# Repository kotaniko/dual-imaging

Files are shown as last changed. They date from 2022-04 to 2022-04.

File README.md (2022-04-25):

# Dual-Imaging Display
This prototype is developed in partial fulfillment for a Master's degree to prove that fiber-optic interconnection is a suitable high-speed interconnection for CubeSat platforms. The thesis is available [here](https://gatech.edu).

## Introduction
This repository contains the development details of dual-imaging display using the BF4M fiber-optic module with FPGAs and Raspberry Pi Compute Module 4. The goal of this prototype is to demonstrate the high-speed interconnection using a fiber-optic transceiver for CubeSat platforms.

## Hardware
* Artix-7 FPGA module from Trenz Electronic: [TE0714-03-50-2IAC6](https://shop.trenz-electronic.de/en/TE0714-03-50-2IAC6-FPGA-Module-with-Xilinx-Artix-7-XC7A50T-2CSG325I-1.8V-Configuration-4-x-3-cm)

* [Raspberry Pi Compute Module 4](https://www.raspberrypi.com/products/compute-module-4)

* [BF4M](https://www.hirose.com/product/series/BF4M) fiber-optic module from Hirose Electronic

* [Pcam 5C](https://digilent.com/shop/pcam-5c-5-mp-fixed-focus-color-camera-module) camera module from Digilent

## System Architecture
Below shows the overview of the dual-imaging display system.

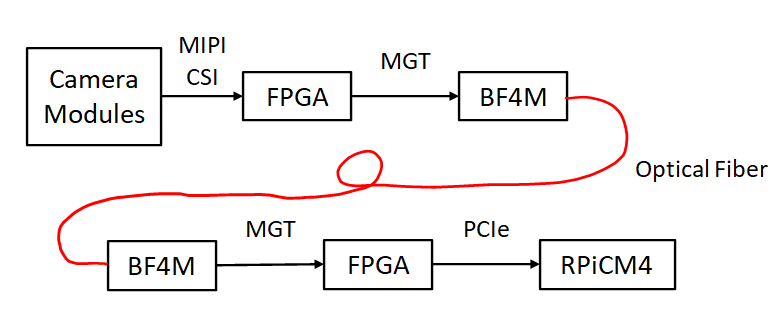
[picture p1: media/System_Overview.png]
System Overview


MIPI CSI-2 Rx Subsystem IP core is used for interfacing with the camera modules, and Aurora8B10B Ip core for interfacing with the fiber-optic transceiver operating up to 6.25 Gbps. On the receiver FPGA, DMA/Bridge Subsystem for PCI Express IP core is used for interfacing with the Raspberry Pi Compute Module 4 over PCIe.

Post-synthesis re-routing on the RX FPGA is needed for GTP clock signals as Aurora8B10B and PCIe core require different clock source. The details are explained in **Vivado/README.md**.

## Images of the Prototype

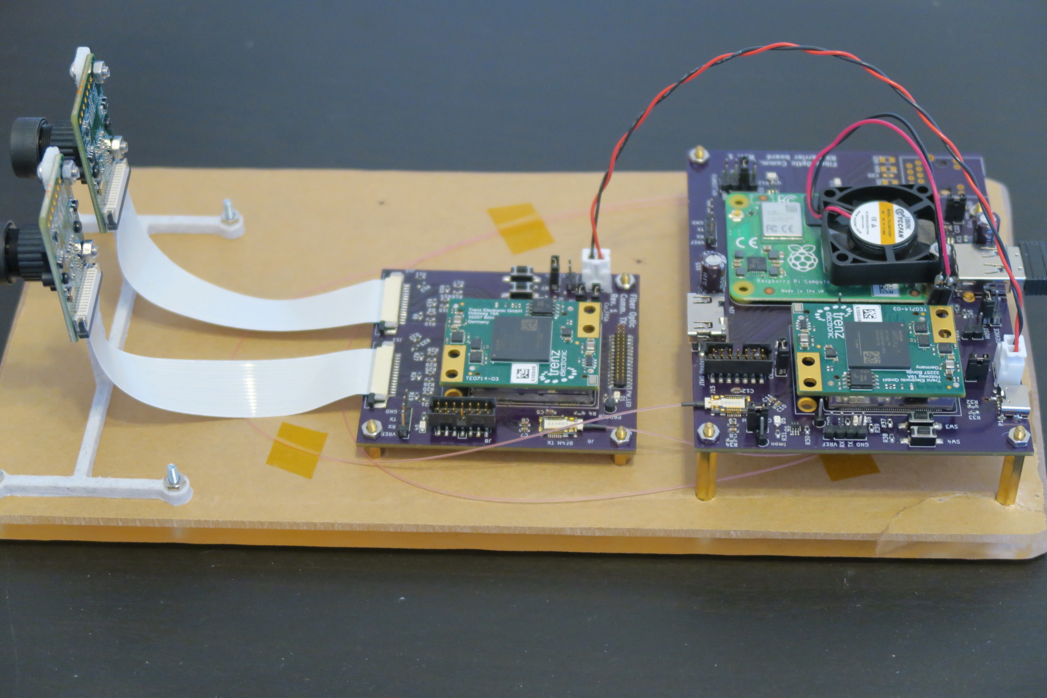
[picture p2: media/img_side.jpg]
Side view


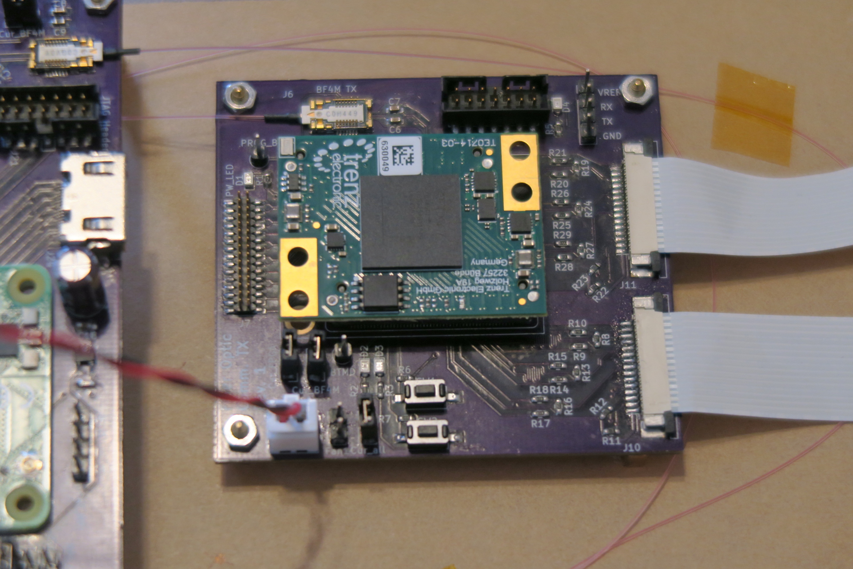
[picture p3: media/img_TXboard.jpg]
TX board


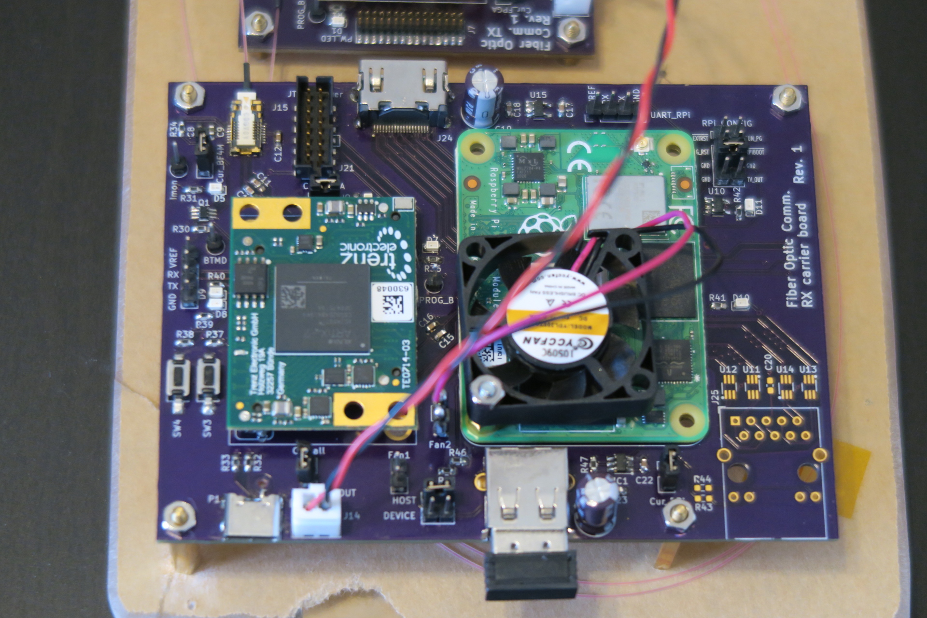
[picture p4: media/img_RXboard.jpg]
RX board


## Demonstration Video
Below video demonstrates that the two camera data stream are transmitted to the Raspberry Pi Compute Module 4 at 1.0 Gbps. The RPiCM4 was capable of receiving the data stream to /dev/null at 2.0 Gbps, but the maximum data rate to write the data stream to its RAM was 1.0 Gbps.

https://user-images.githubusercontent.com/22487346/164984304-3e48e70a-c83b-4c12-9497-3e3b185fa539.mov

The validation method discussed in the thesis demonstrated that the BF4M fiber-optic module achieved the maximum data rate of 6.25 Gbps at the power consumption of 90 mW.

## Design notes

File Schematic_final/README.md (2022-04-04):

# Schematic of the final prototype board

CAD design software: KiCad 6.0

The signals shown below are re-routed after fabrication. This directory contains the modified schematic design. The pdf of the schematic is available in ../Docs directory.

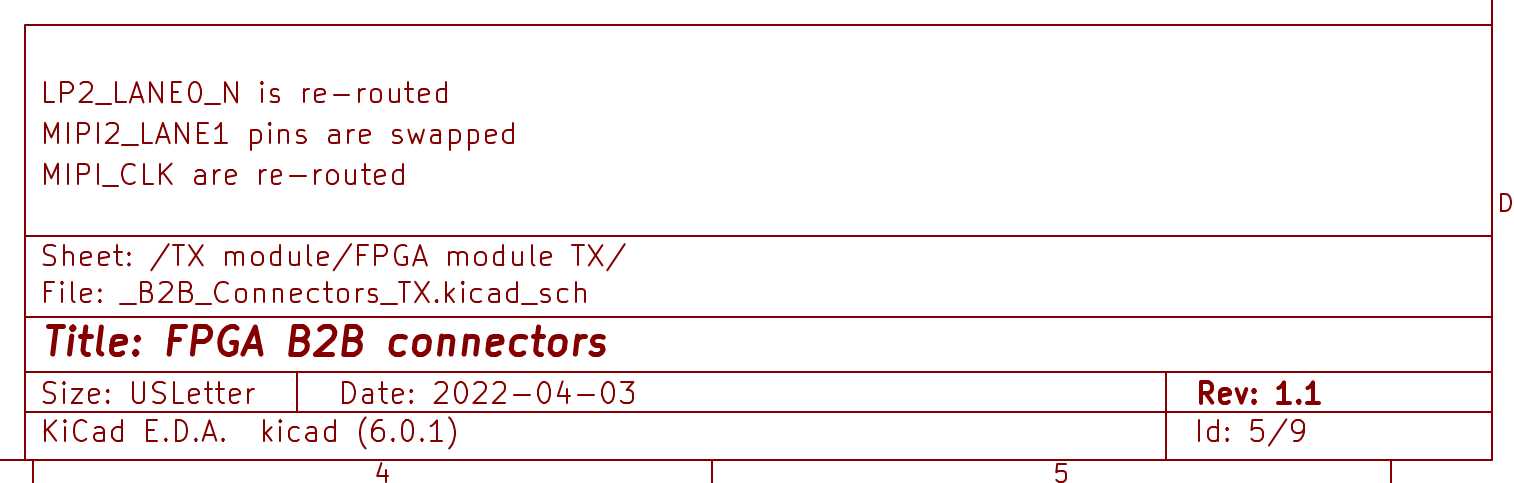
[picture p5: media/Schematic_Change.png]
Schematic Change


Open Root.kicad_pro project file with KiCad 6.0 to design this schematic.

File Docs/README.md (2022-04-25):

# Document

* BlockDesign_aurora2pcie.pdf
    - Block design of the RX FPGA
* BlockDesign_mipiCsi2aurora.pdf
    - Block design of the TX FPGA
* Schematic_fabricated.pdf
    - Schematic of the fabricated PCB
* Schematic_final.pdf
    - Final schematic of the prototype board as some signals are re-routed after fabrication

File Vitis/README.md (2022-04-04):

# Vitis development

Software: Vitis 2021.2

Run createVitisProject.bat to build an application project for the TX board (Windows only). This batch file runs create_project_mipiCsi2aurora.tcl script.

After the project is successfully built, the script launches the Vitis, and the welcome page shown below appears.

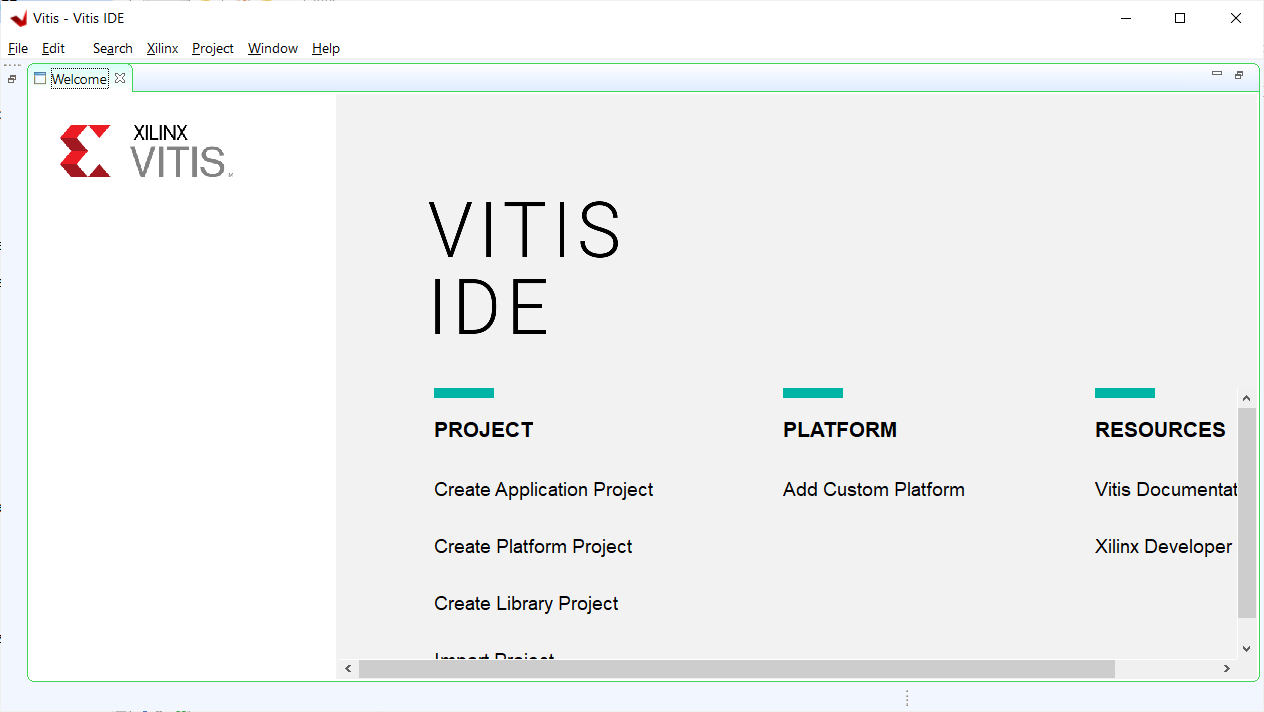
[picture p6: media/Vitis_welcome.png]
Vitis welcome page


Close the welcome page, and you will see the application project shown below.

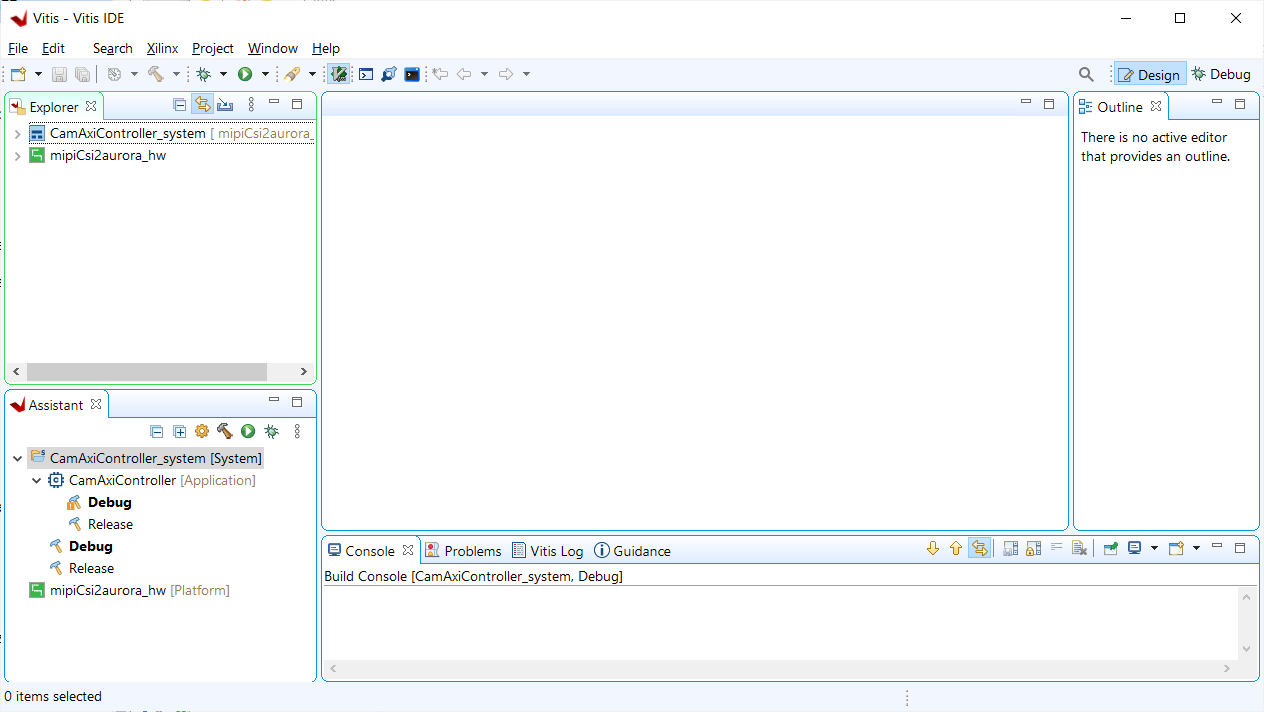
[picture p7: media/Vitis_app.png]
Vitis app page


You can now start working on the software development for Microblaze integrated in the TX board.

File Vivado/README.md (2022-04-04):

# Vivado Development

Software: Vivado 2021.2

Run create_project_mipiCsi2aurora.bat to build a Vivado project for the TX board (Windows only). This batch file runs create_project_mipiCsi2aurora.tcl script. Similarly, run create_project_aurora2pcie.bat to build a Vivado project for the RX board. Running the project creation tcl scripts for other version of Vivado may produce error upon execution. Modify the tcl scripts accordingly by replacing the version number with the appropriate one.

Successful execution of the script will launch the Vivado project looking similar to the below.

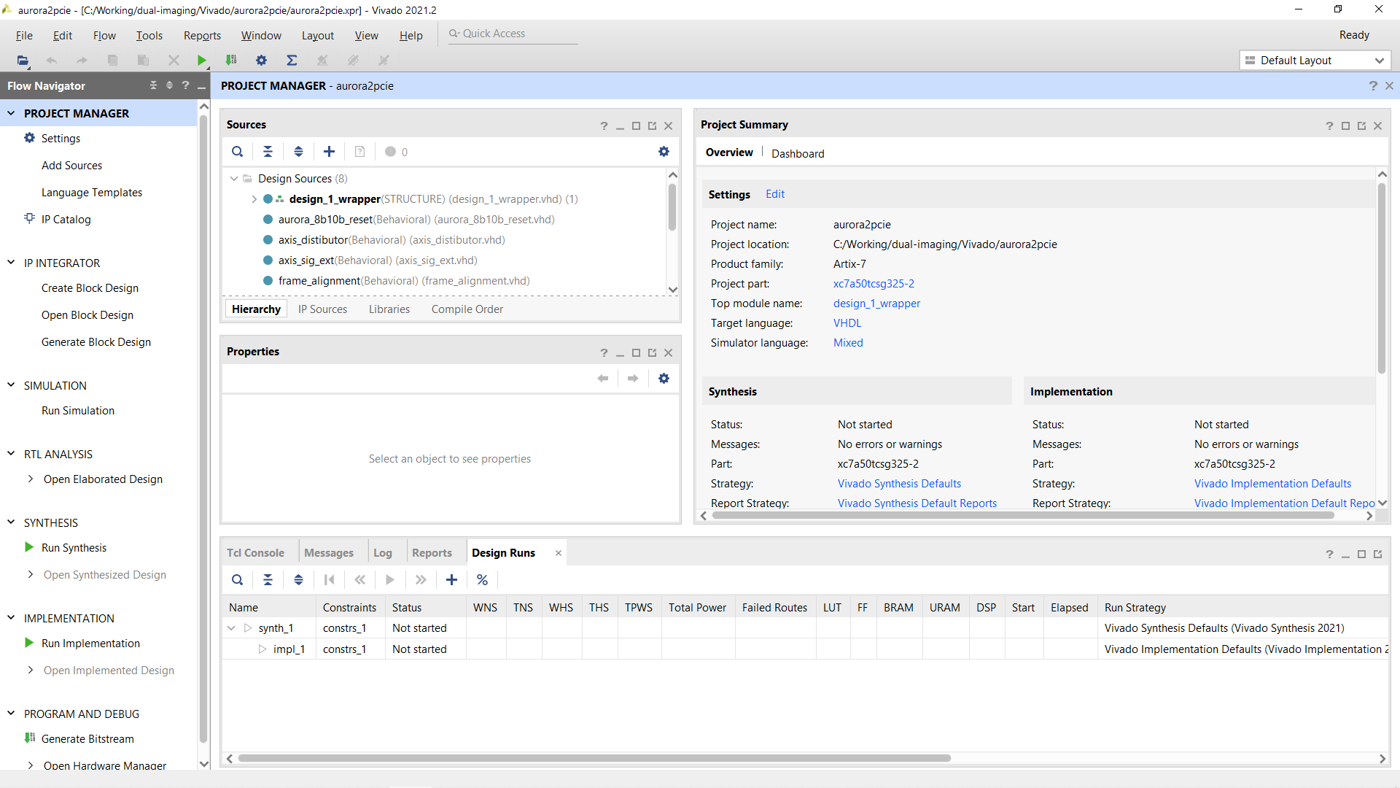
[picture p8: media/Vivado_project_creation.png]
Vivado Project Creation


create_BD_[mipiCsi2aurora/aurora2pcie].tcl are available for those who want to just create the block design. Overviews of the block design for TX/RX board are available under ../Docs directory.

## Directories

* bitstream
    - bitstream files for the TX/RX board generated by Vivado

* hardwareDesign
    - FPGA hardware binary for the TX board exported from Vivado

* memoryConfig
    - memory contents for flash memory on the TE0714 module

* my_constrs/my_rtl/my_tcl
    - source files used in the projects, mipiCsi2aurora and aurora2pcie

## aurora2pcie Project Guide

The Aurora8B10B and PCIe core uses PLL0 by default. Since they require different clock frequency, one of them must use PLL1. This conflict is addressed by running tcl command after synthesis.

After completing the synthesis, open synthesized design as shown below.

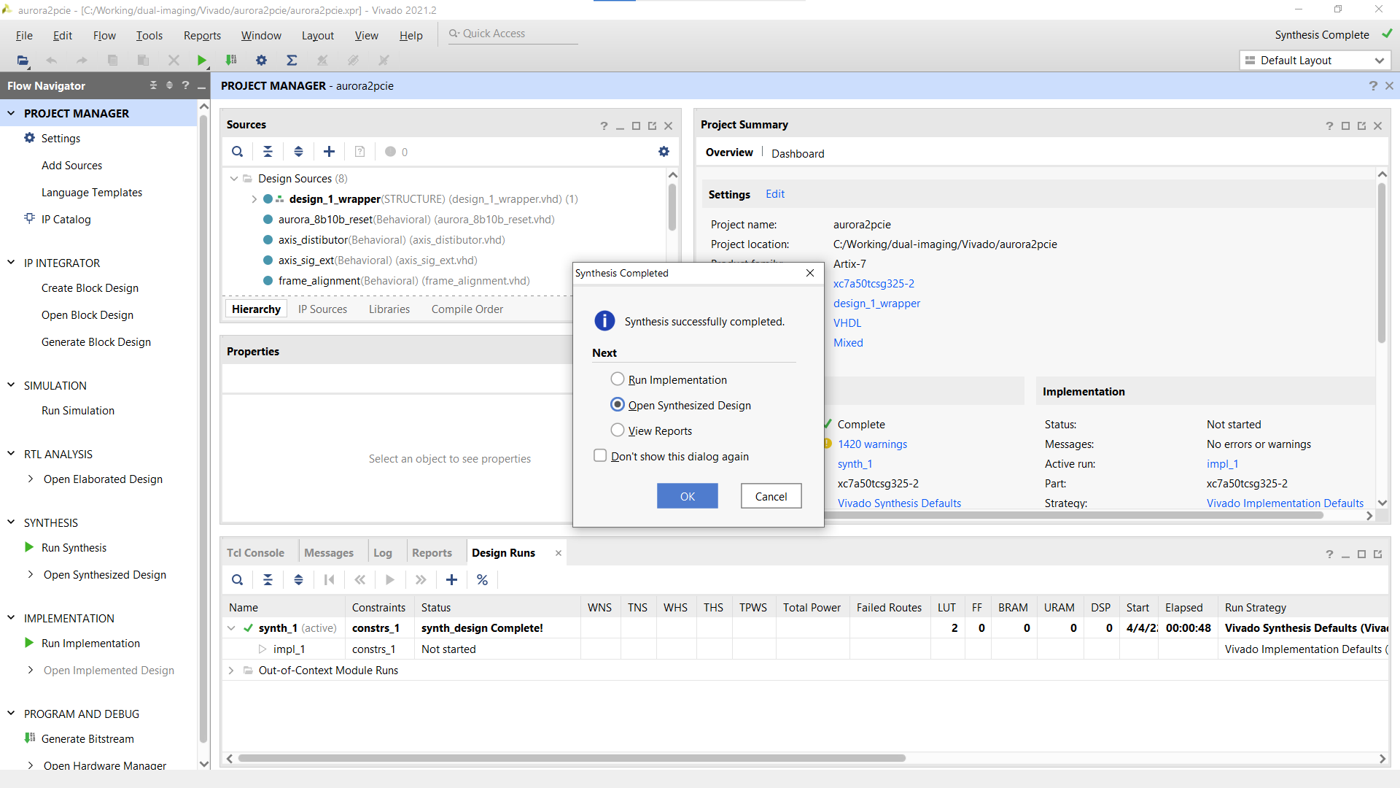
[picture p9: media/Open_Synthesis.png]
Open Synthesis


This will open the Synthesized Design window. Run my_tcl/aurora_pll1.tcl or copy and paste the content of my_tcl/aurora_pll1.tcl in Tcl Console to make the aurora8B10B IP core on the RX board to use PLL1 instead of PLL0.

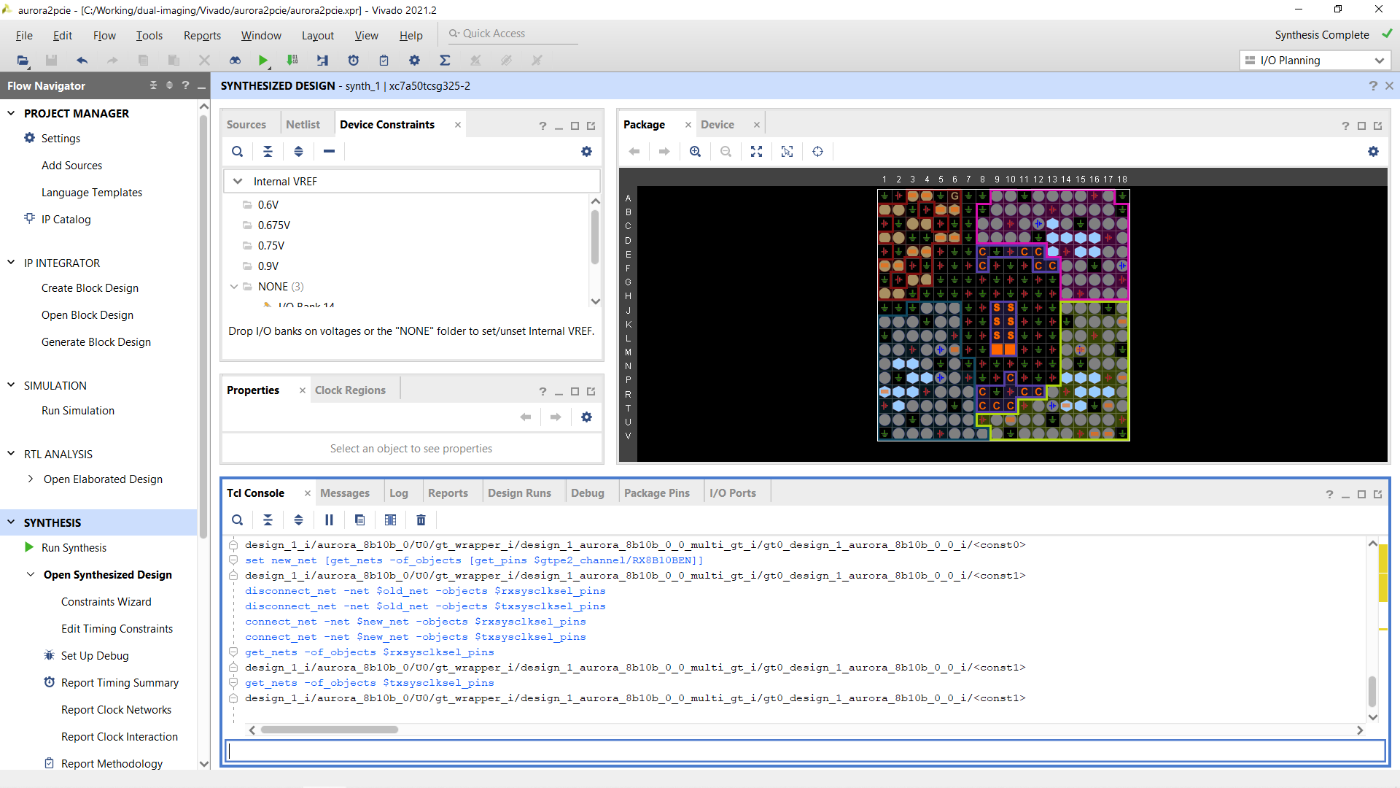
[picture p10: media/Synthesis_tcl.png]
tcl command


Successful execution of the tcl commands should re-route the RXSYSCLKSEL of the GTPE2_CHANNEL primitive to b'11.

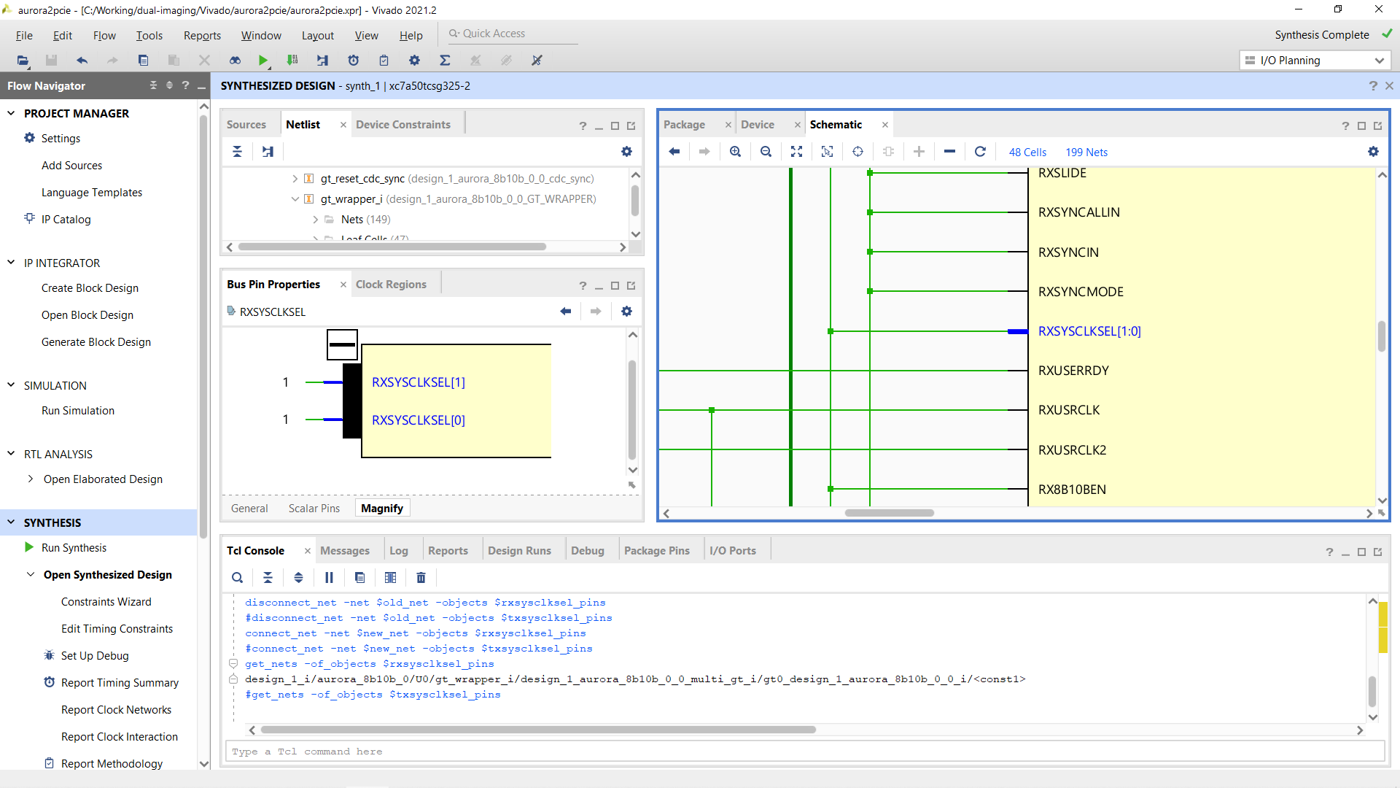
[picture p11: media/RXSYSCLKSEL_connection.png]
RXSYSCLKSEL Connection


Then, continue to run Implementation while the Synthesized Design window opened. Since the synthesized designed is opened in-memory, the net change applied by the above tcl command is also in-memory. Closing the Synthesized Design window will lose the change, and Vivado will implement the design with the original design.

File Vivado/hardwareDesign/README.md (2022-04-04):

# Hardware Design

TX board FPGA hardware binary exported from Vivado

Import *.xsa file in Vitis to create a platform.

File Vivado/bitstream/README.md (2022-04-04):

# Bitstream

Upload mipiCsi2aurora.bit or aurora2pcie.bit to the TX/RX board, respectively, with Vivado Hardware Manager.

*.ltx is a probe file to use VIO and ILA cores from Vivado Hardware Manager.

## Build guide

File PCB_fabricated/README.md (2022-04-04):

# Design files for fabricated PCB

CAD design software: KiCad 6.0

The 3D images of the TX and RX board are shown below. The pdf of the schematic is available in ../Docs directory.

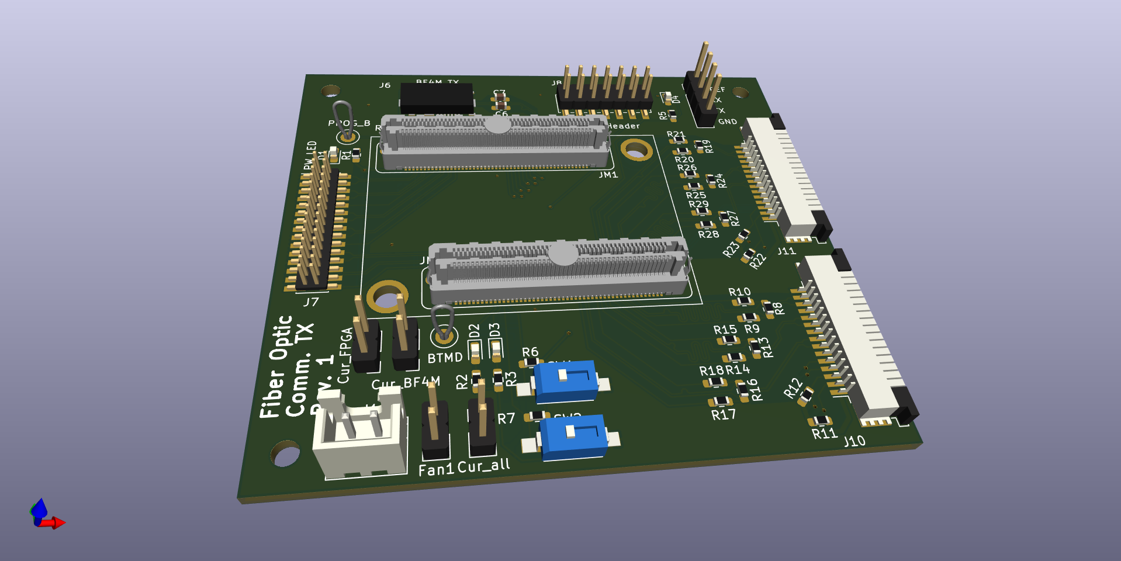
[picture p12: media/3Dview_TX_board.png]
TX board 3d image


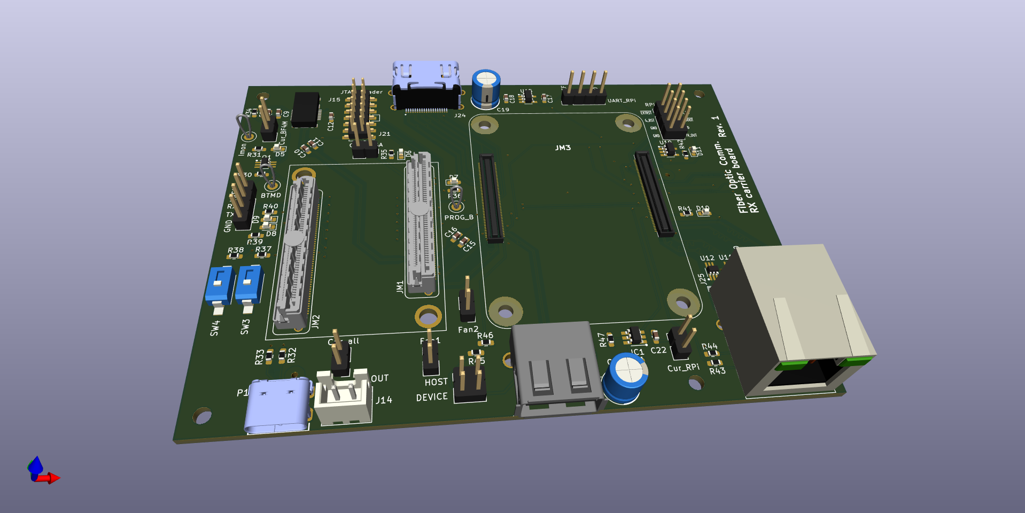
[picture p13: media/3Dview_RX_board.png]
RX board 3d image


Open Root.kicad_pro to design the schematic and [TX/RX]_module.kicad_pro to design [TX/RX] board PCB.

mylib directory contains the project specific symbol, footprint, and 3D model.

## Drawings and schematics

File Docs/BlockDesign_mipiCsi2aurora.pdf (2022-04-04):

### aurora_8b10b_0

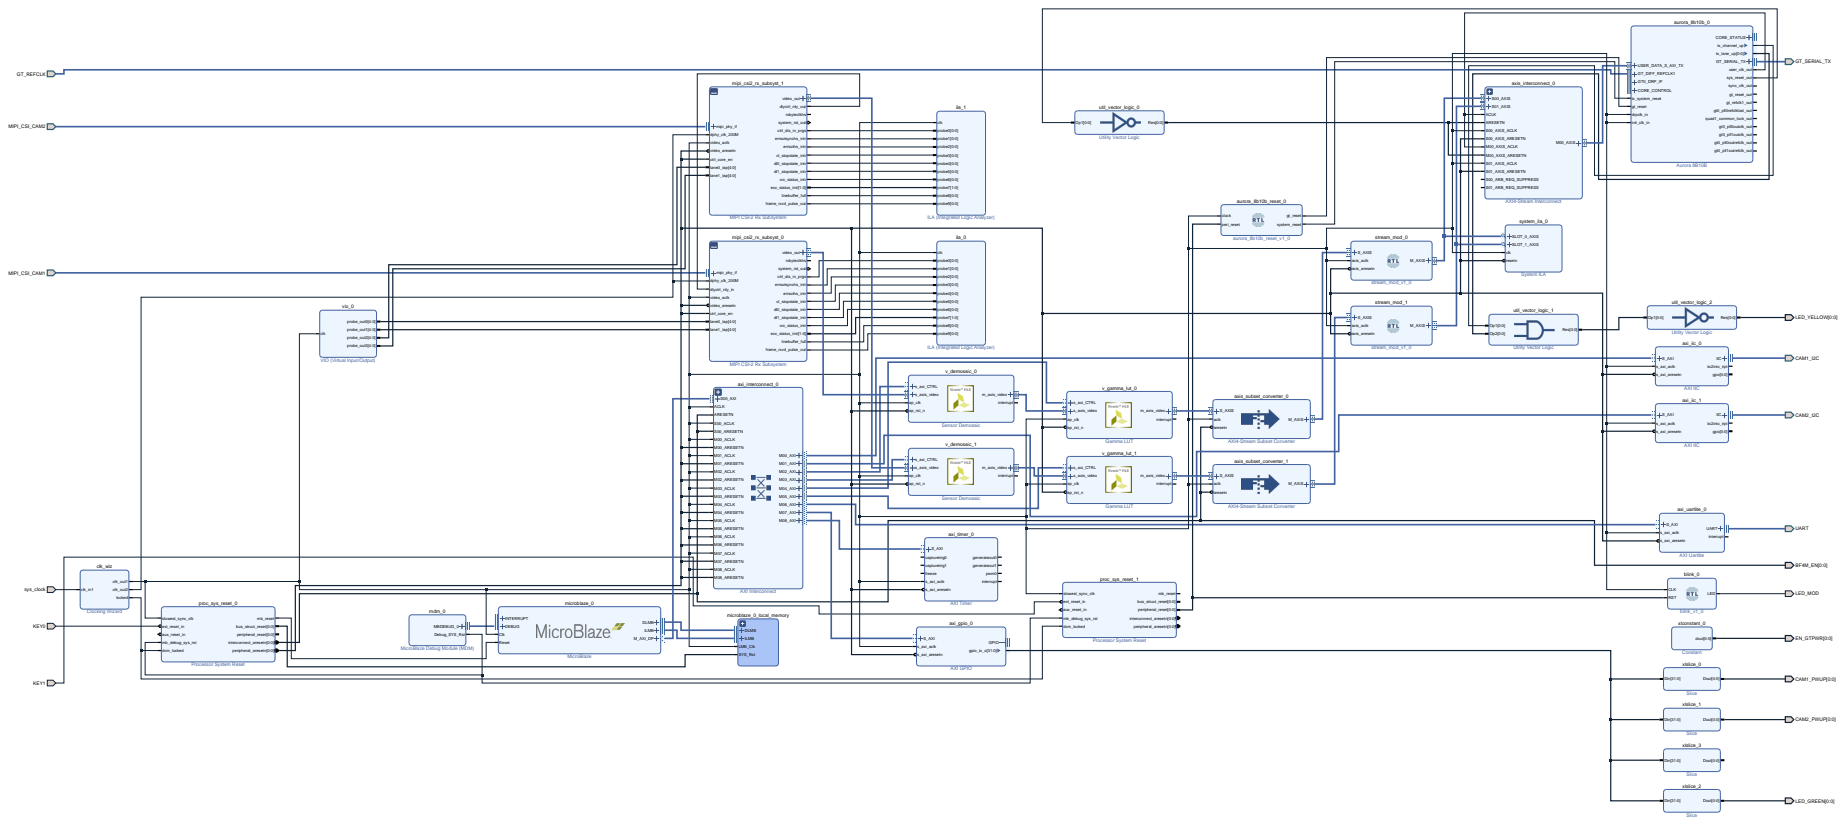
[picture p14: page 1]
CAM1_I2C; CAM1_PWUP[0:0]; CAM2_I2C; CAM2_PWUP[0:0]; EN_GTPWR[0:0]; GT_REFCLK; GT_SERIAL_TX; LED_GREEN[0:0]; LED_YELLOW[0:0]; MIPI_CSI_CAM1; MIPI_CSI_CAM2; UART; aurora_8b10b_reset_0; aurora_8b10b_reset_v1_0; clock peri_reset; gt_reset system_reset; Aurora 8B10B; USER_DATA_S_AXI_TX GT_DIFF_REFCLK1 GT0_DRP_IF; CORE_STATUS; tx_channel_up; tx_lane_up[0:0]; CORE_CONTROL; tx_system_reset gt_reset drpclk_in; init_clk_in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

Utility Vector Logic

MIPI CSI-2 Rx Subsystem

ILA (Integrated Logic Analyzer)
clk probe0[0:0] probe1[0:0] probe2[0:0] probe3[0:0] probe4[0:0] probe5[0:0] probe6[0:0] probe7[1:0] probe8[0:0] probe9[0:0]

axi_iic_0

VIO (Virtual Input/Output)

AXI4-Stream Subset Converter

Processor System Reset

MicroBlaze Debug Module (MDM)

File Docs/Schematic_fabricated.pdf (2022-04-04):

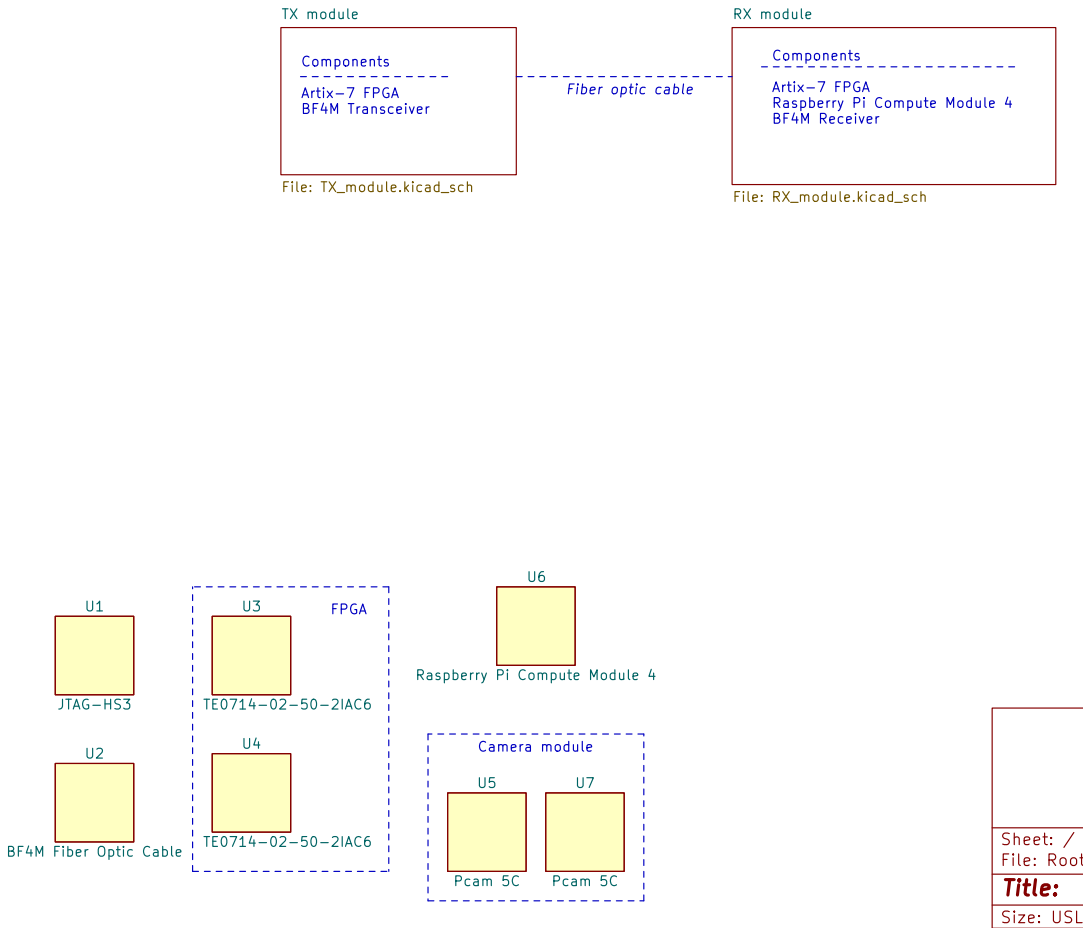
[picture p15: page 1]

Components Artix-7 FPGA Raspberry Pi Compute Module 4 BF4M Receiver Components Artix-7 FPGA

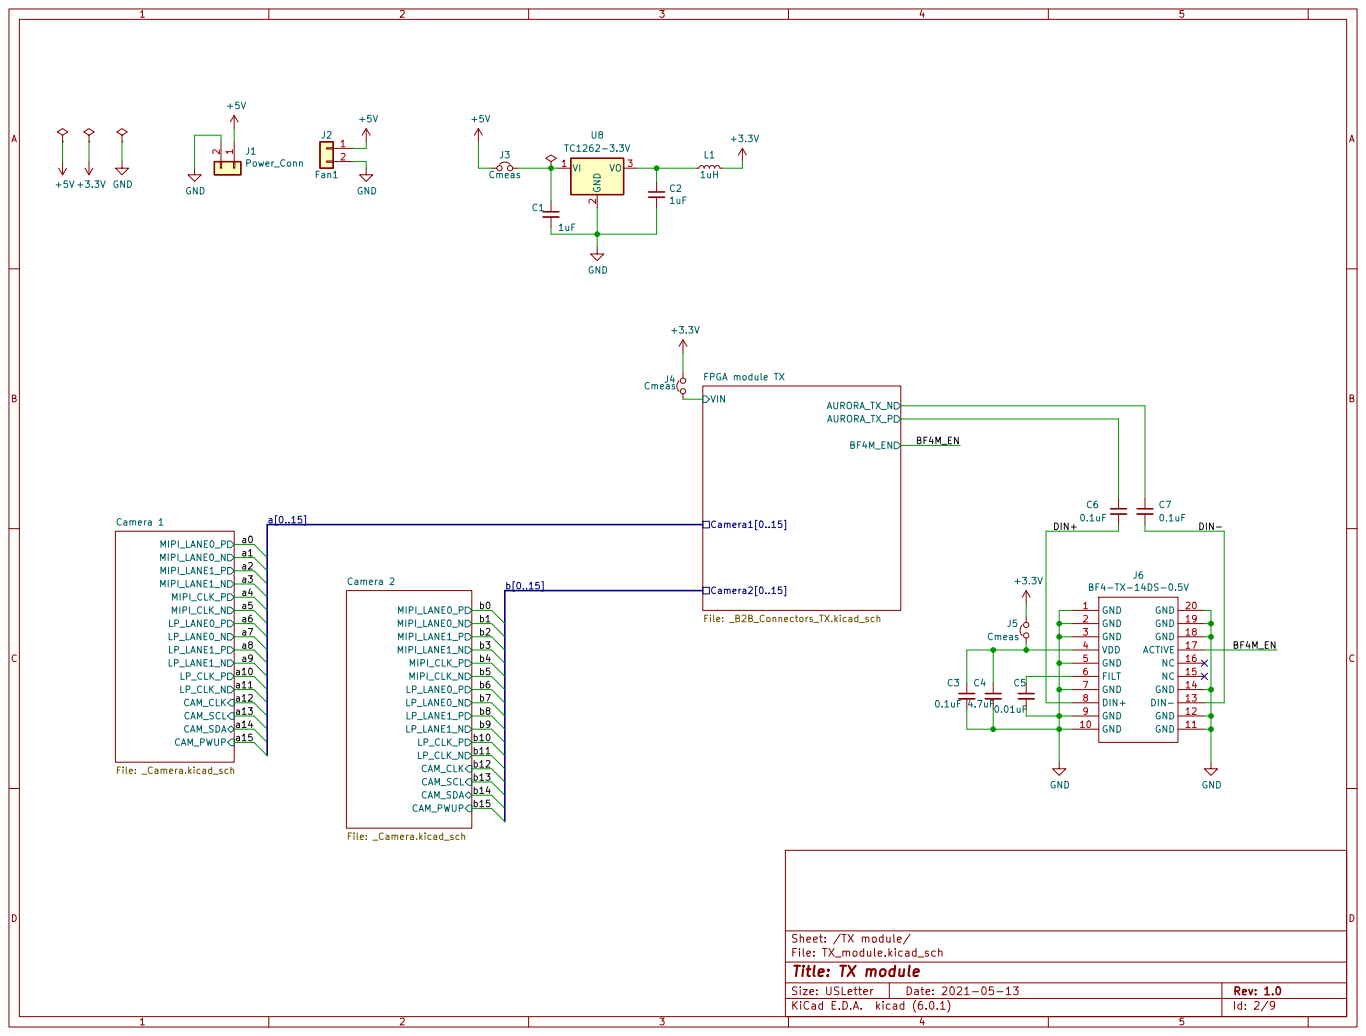
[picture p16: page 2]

File: TX_module.kicad_sch Sheet: /TX module/ MIPI_LANE0_N MIPI_LANE0_P MIPI_LANE1_N MIPI_LANE1_P MIPI_CLK_N MIPI_CLK_P CAM_PWUP CAM_CLK CAM_SCL CAM_SDA

Id: 2/9 Title: TX module

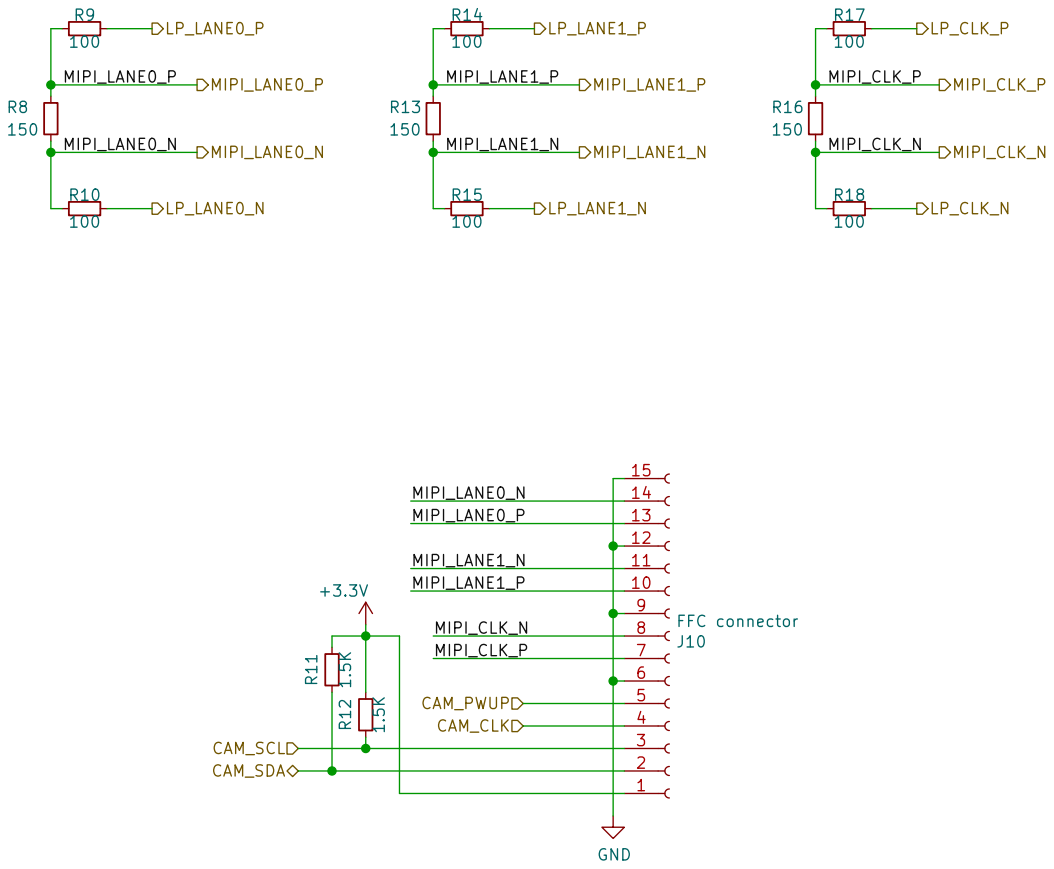
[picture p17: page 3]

Id: 3/9 Title: Camera module

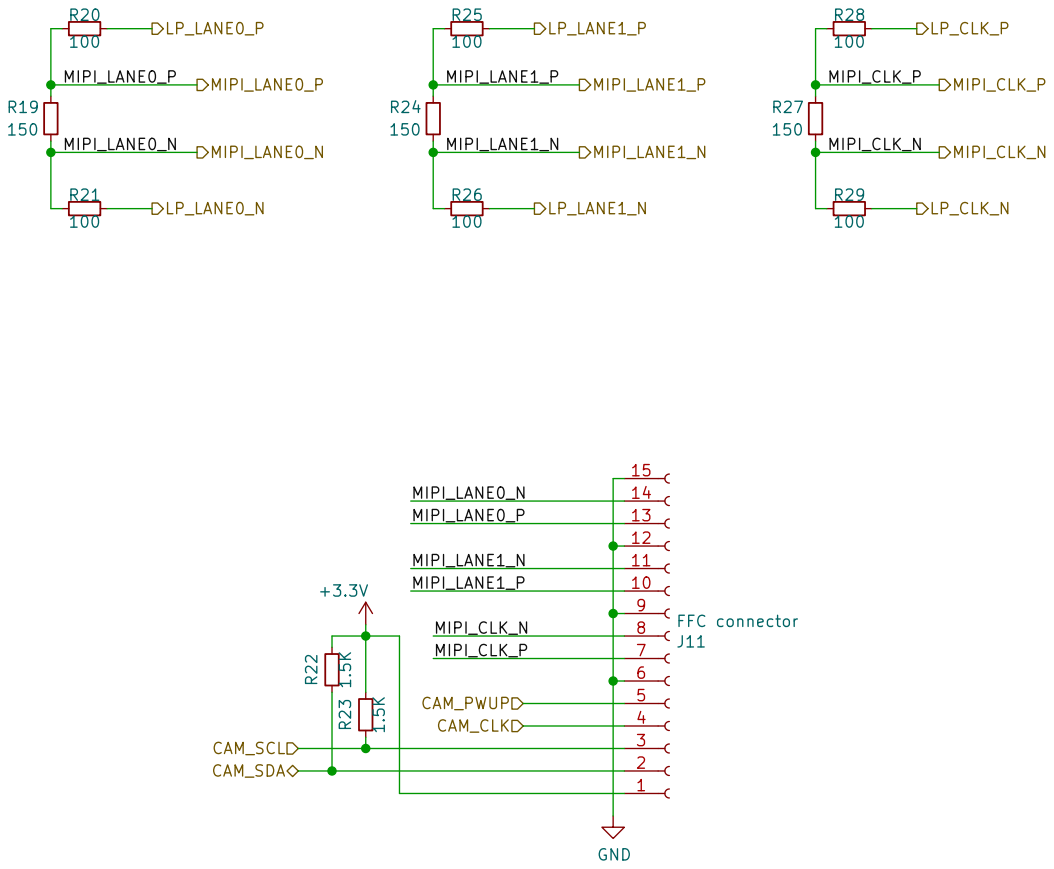
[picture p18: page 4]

Id: 4/9 Title: Camera module

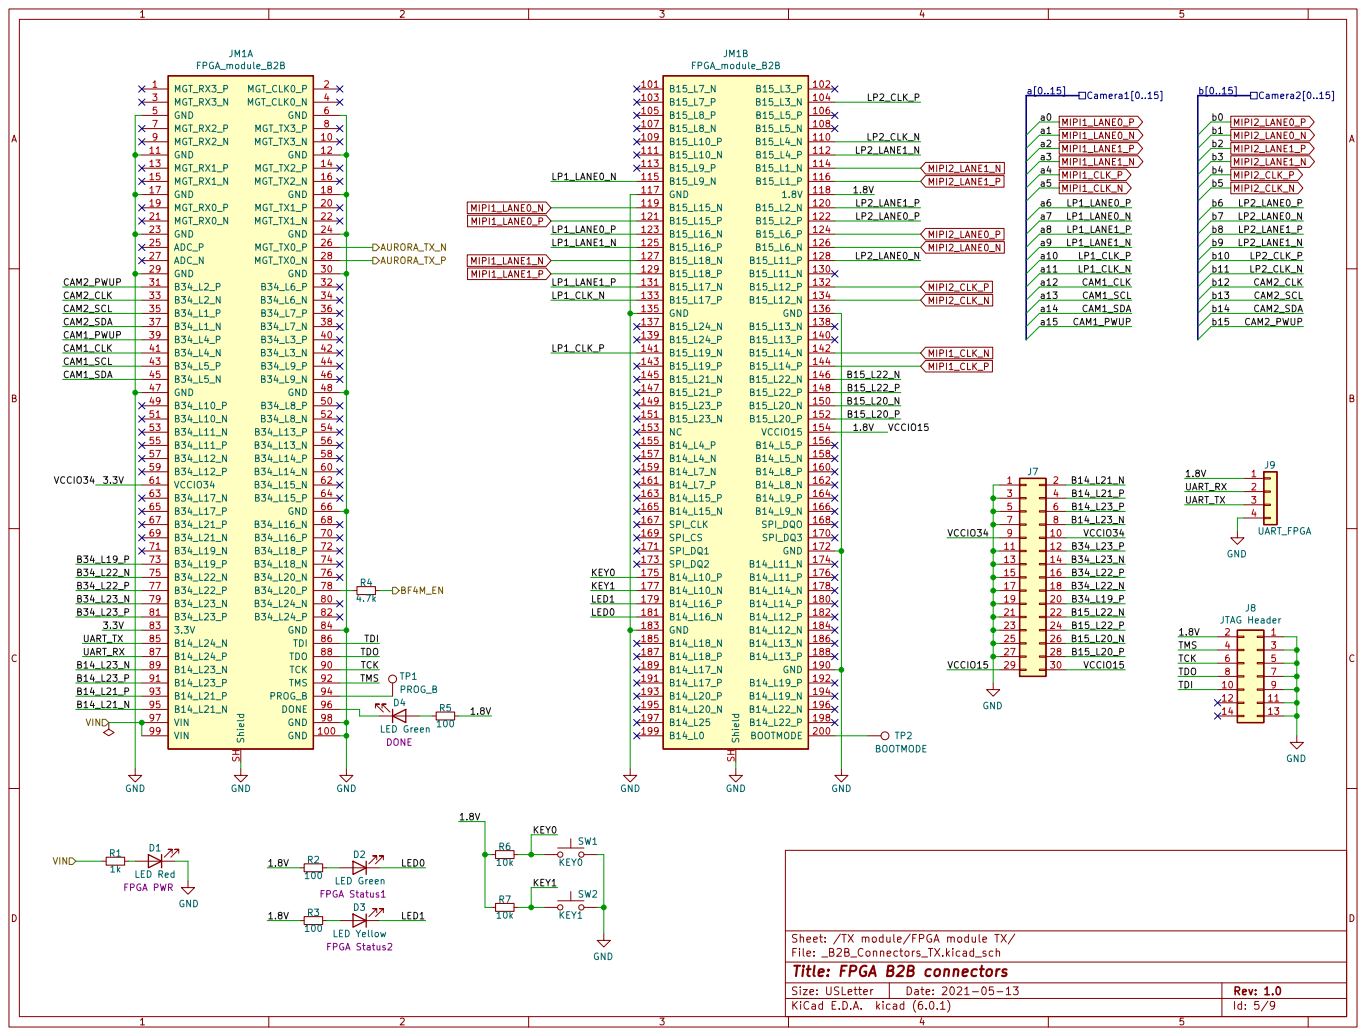
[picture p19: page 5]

Id: 5/9 Title: FPGA B2B connectors

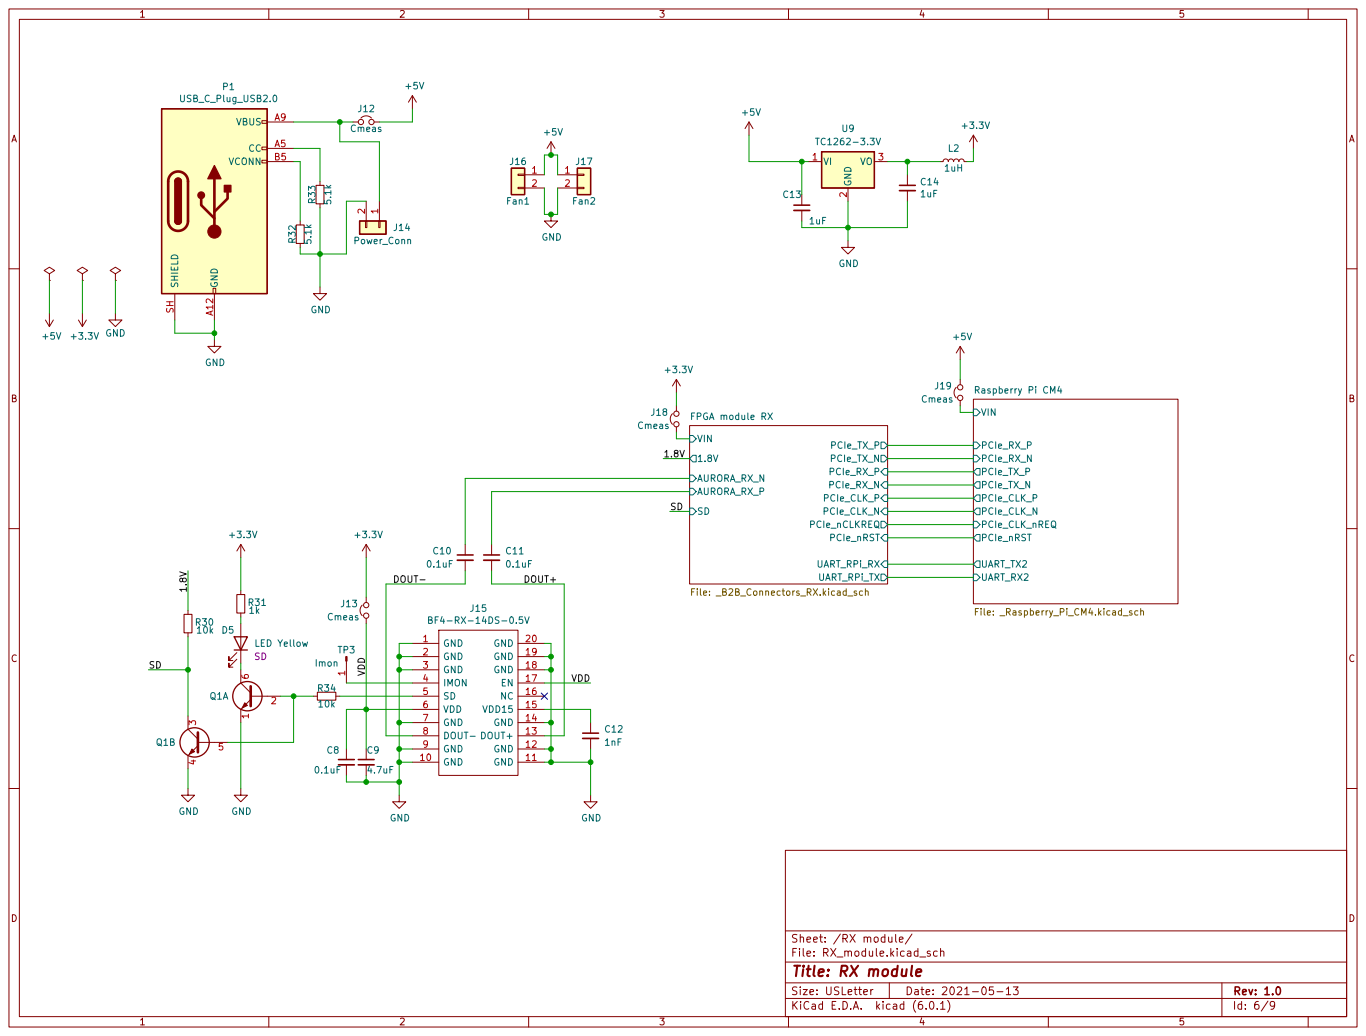
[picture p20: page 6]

Id: 6/9 Title: RX module

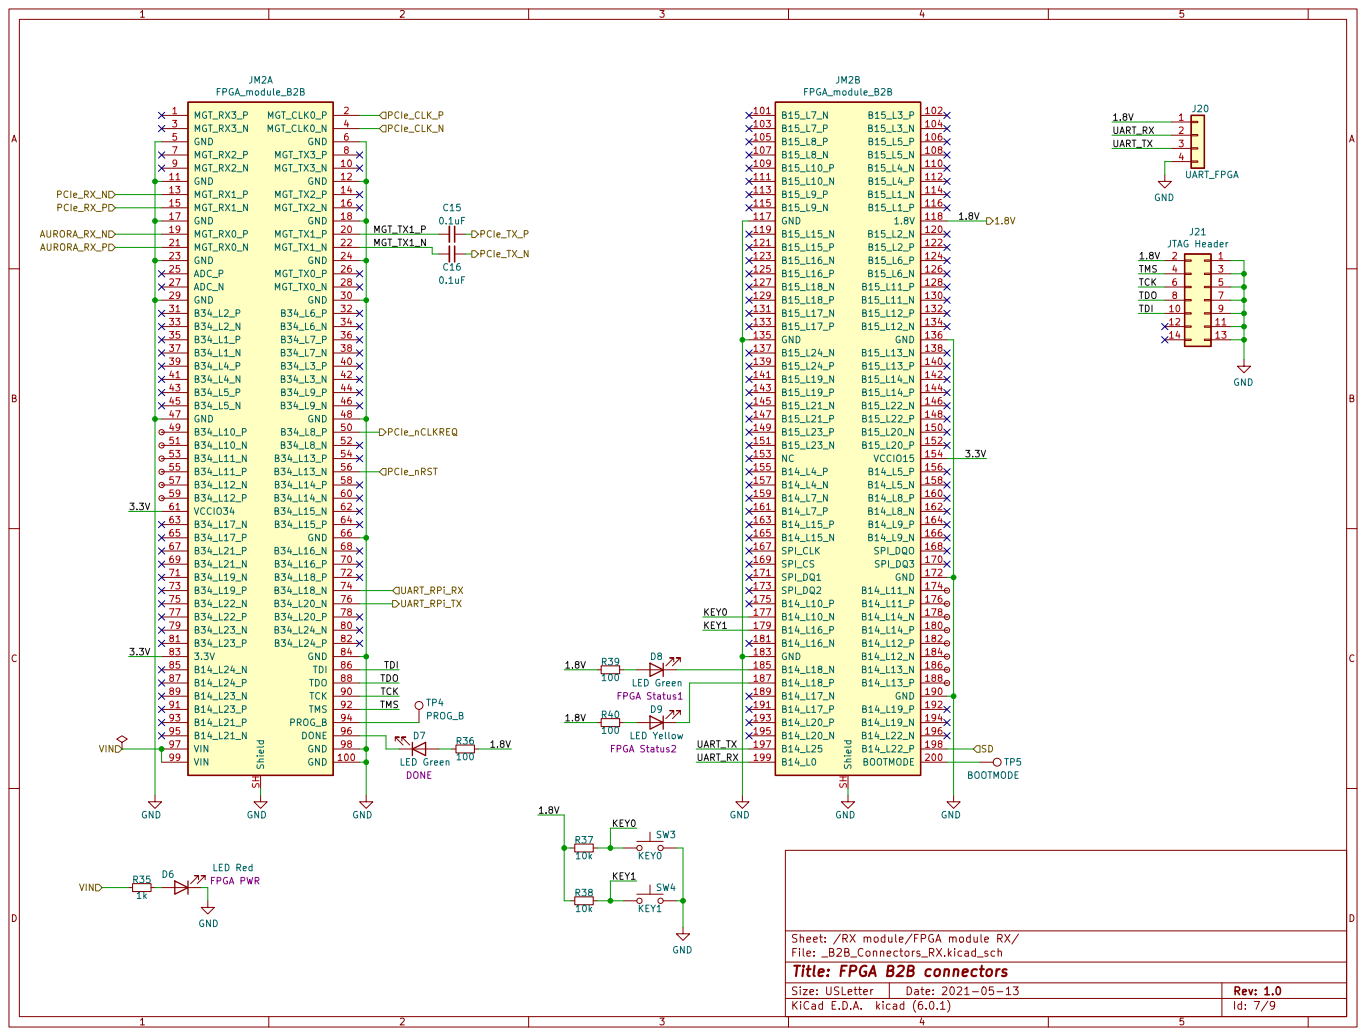
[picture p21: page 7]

JTAG Header Shield SH

File: _B2B_Connectors_RX.kicad_sch Sheet: /RX module/FPGA module RX/ GND

Id: 7/9 Title: FPGA B2B connectors

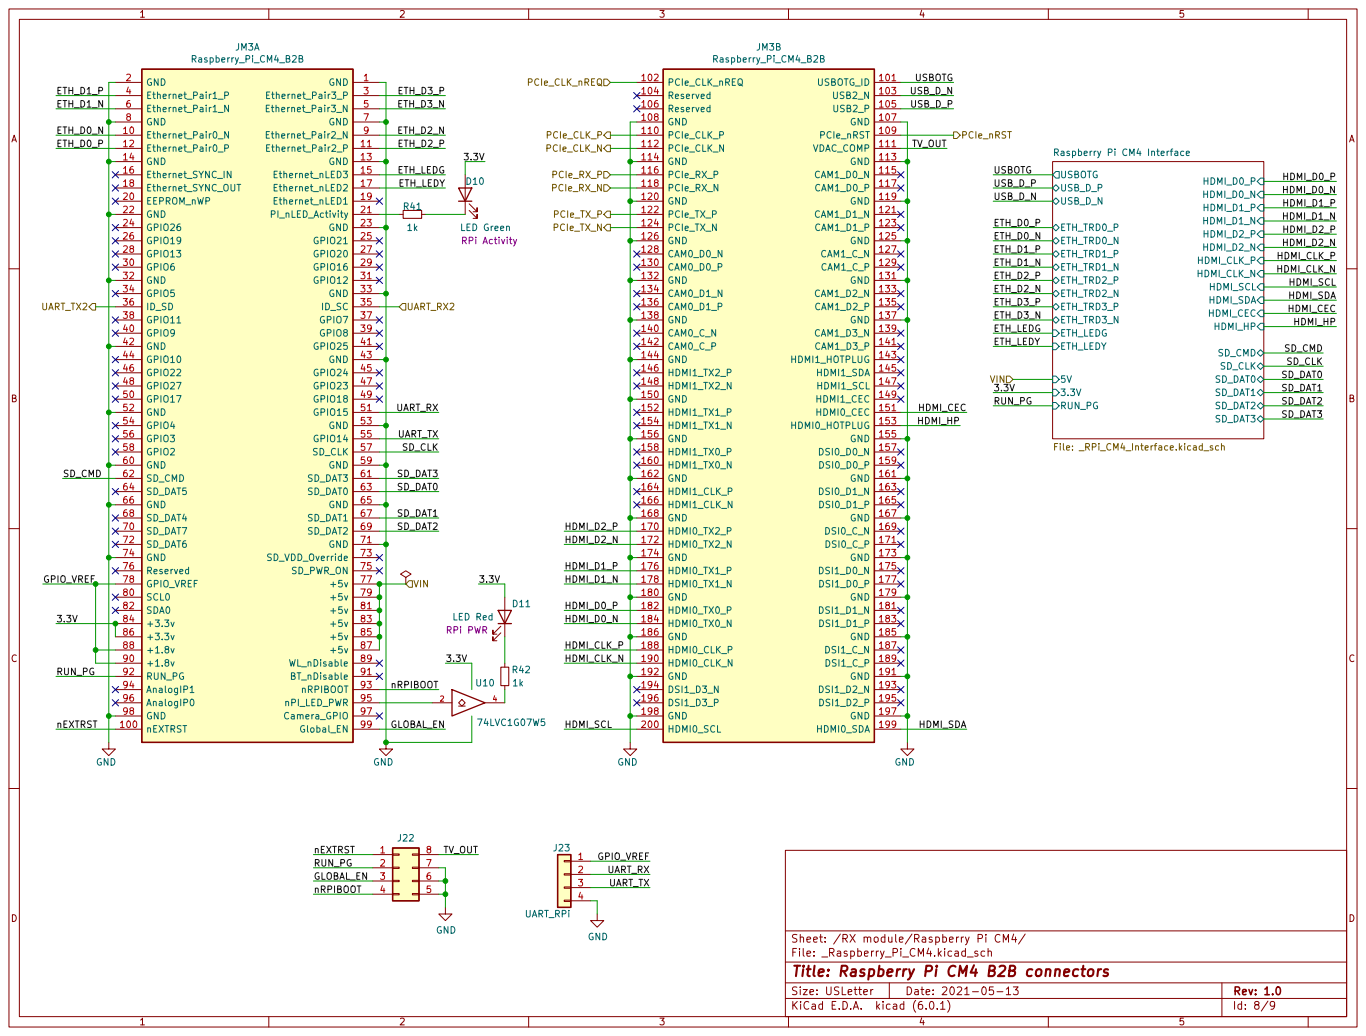
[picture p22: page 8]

SD_DAT0 SD_DAT1 Raspberry Pi CM4 Interface File: _RPi_CM4_Interface.kicad_sch GND

Sheet: /RX module/Raspberry Pi CM4/
File: _Raspberry_Pi_CM4.kicad_sch
Id: 8/9 Title: Raspberry Pi CM4 B2B connectors

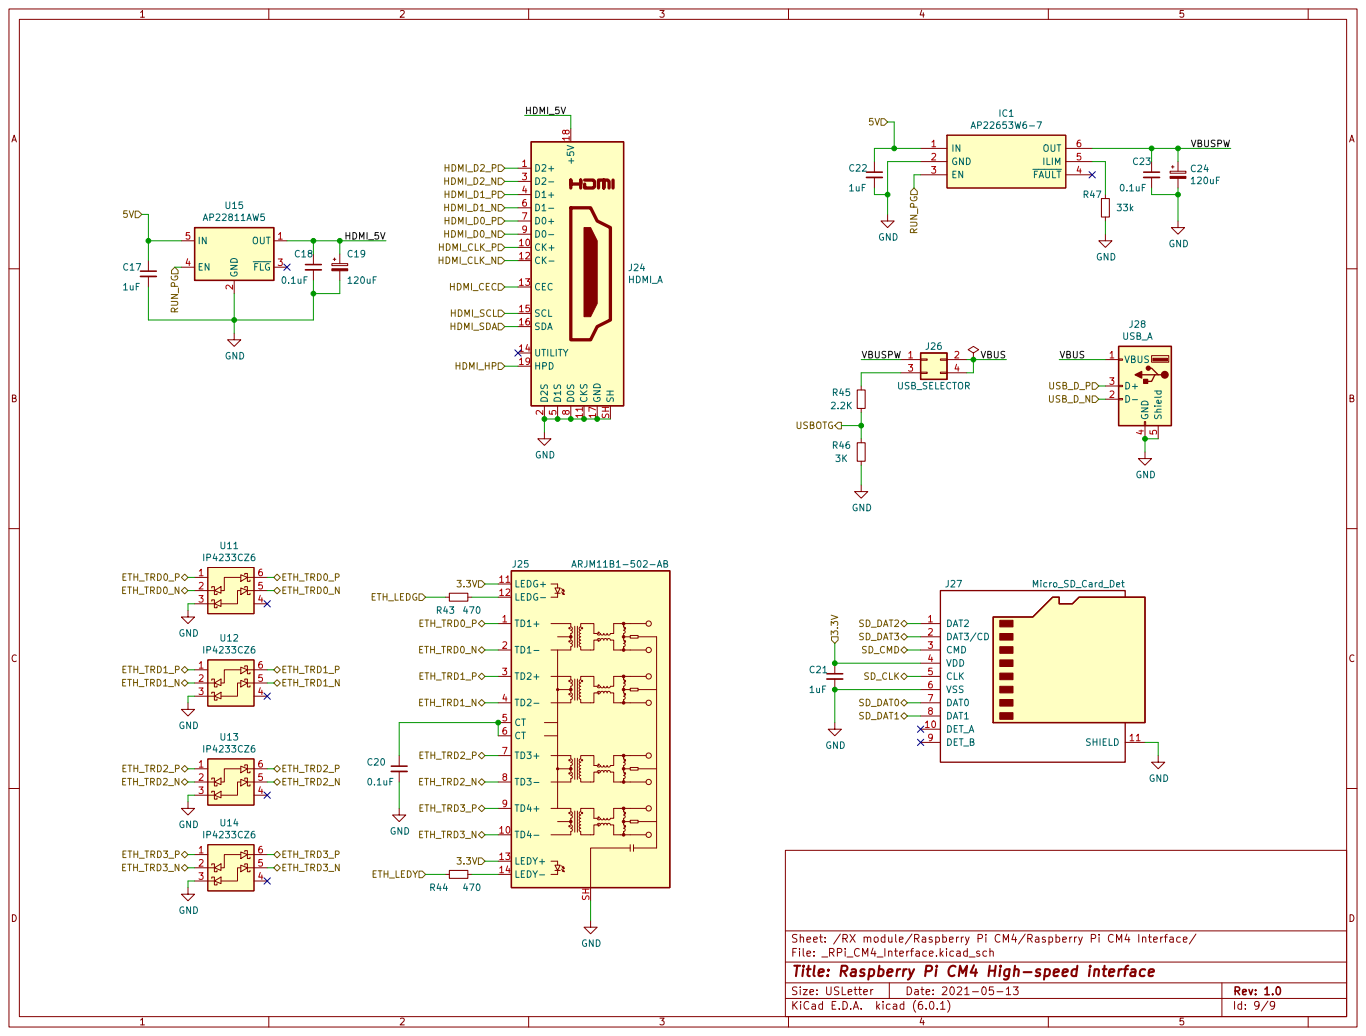
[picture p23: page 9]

Sheet: /RX module/Raspberry Pi CM4/Raspberry Pi CM4 Interface/ 1

File: _RPi_CM4_Interface.kicad_sch
Id: 9/9 Title: Raspberry Pi CM4 High-speed interface

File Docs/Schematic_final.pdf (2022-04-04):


Components Artix-7 FPGA Raspberry Pi Compute Module 4 BF4M Receiver Components Artix-7 FPGA


File: TX_module.kicad_sch Sheet: /TX module/ MIPI_LANE0_N MIPI_LANE0_P MIPI_LANE1_N MIPI_LANE1_P MIPI_CLK_N MIPI_CLK_P CAM_PWUP CAM_CLK CAM_SCL CAM_SDA

Id: 2/9 Title: TX module


Id: 3/9 Title: Camera module


Id: 4/9 Title: Camera module

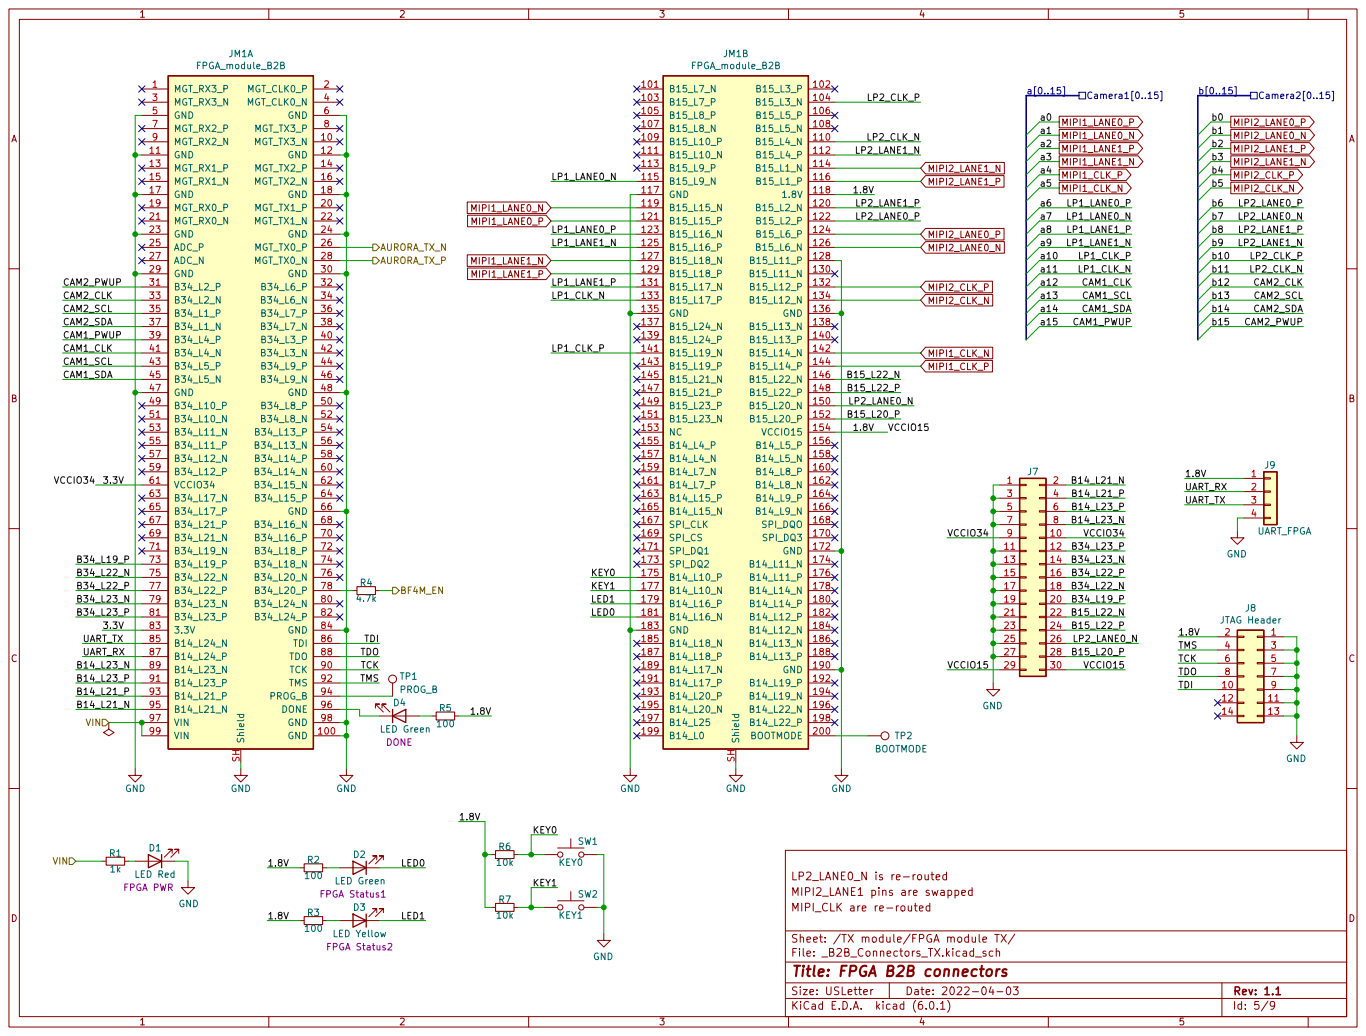
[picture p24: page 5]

LP2_LANE0_N is re-routed GND

LED Red FPGA PWR

MIPI2_LANE1 pins are swapped
File: _B2B_Connectors_TX.kicad_sch Sheet: /TX module/FPGA module TX/ MIPI_CLK are re-routed

Id: 5/9 Title: FPGA B2B connectors


Id: 6/9 Title: RX module


JTAG Header Shield SH

File: _B2B_Connectors_RX.kicad_sch Sheet: /RX module/FPGA module RX/ GND

Id: 7/9 Title: FPGA B2B connectors


SD_DAT0 SD_DAT1 Raspberry Pi CM4 Interface File: _RPi_CM4_Interface.kicad_sch GND

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


Sheet: /RX module/Raspberry Pi CM4/Raspberry Pi CM4 Interface/ 1

File: _RPi_CM4_Interface.kicad_sch
Id: 9/9 Title: Raspberry Pi CM4 High-speed interface

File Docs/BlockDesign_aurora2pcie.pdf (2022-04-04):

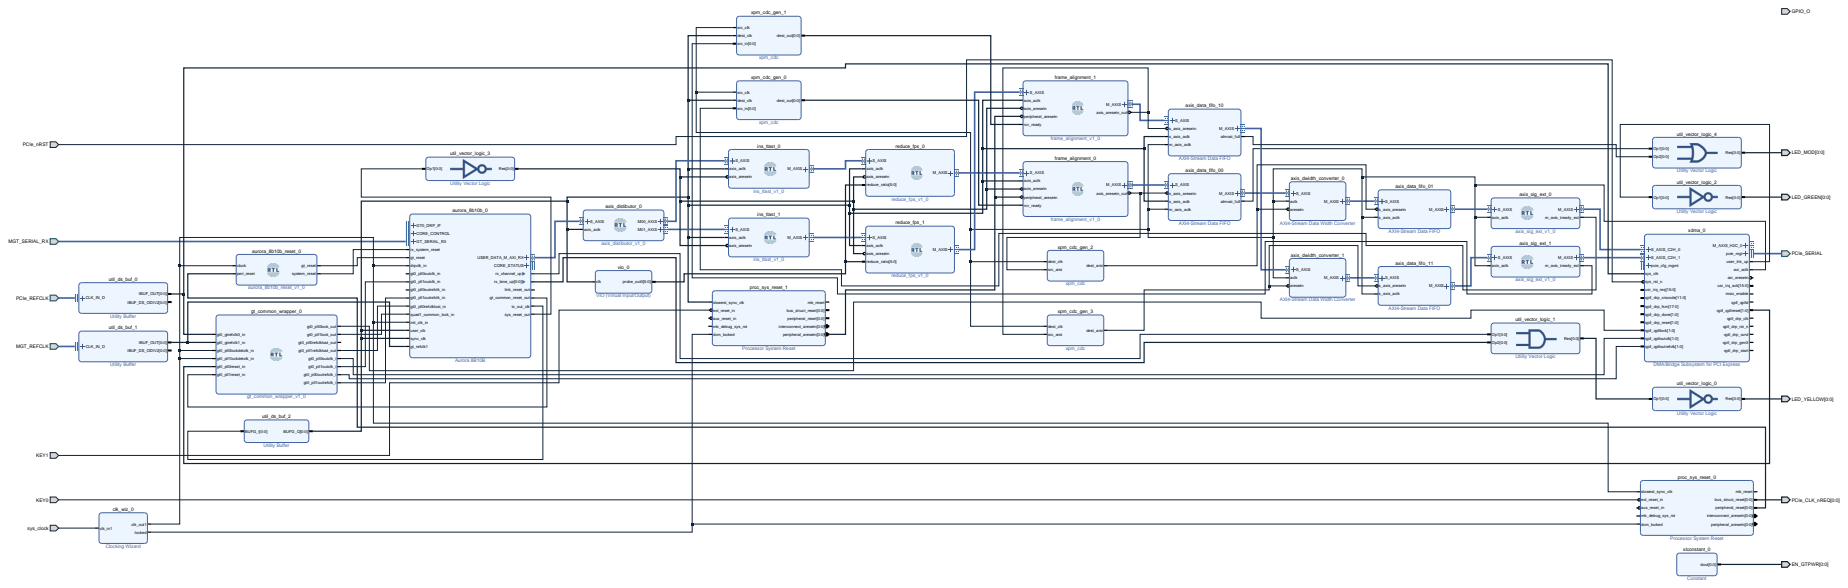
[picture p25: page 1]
PCIe_nRST; MGT_SERIAL_RX; PCIe_REFCLK; MGT_REFCLK; KEY1; KEY0; sys_clock; util_ds_buf_0; Utility Buffer; CLK_IN_D; IBUF_OUT[0:0]; IBUF_DS_ODIV2[0:0]; util_ds_buf_1; clk_wiz_0; Clocking Wizard; clk_in1; clk_out1; locked; aurora_8b10b_reset_0; aurora_8b10b_reset_v1_0; clock peri_reset; gt_reset system_reset; gt_common_wrapper_0; gt_common_wrapper_v1_0; gt0_gtrefclk0_in; gt0_gtrefclk1_in; gt0_pll0lock_out gt0_pll1lock_out; gt0_pll0lockdetclk_in; gt0_pll1lockdetclk_in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

AXI4-Stream Data FIFO

Utility Vector Logic

AXI4-Stream Data Width Converter

VIO (Virtual Input/Output)

Processor System Reset

DMA/Bridge Subsystem for PCI Express

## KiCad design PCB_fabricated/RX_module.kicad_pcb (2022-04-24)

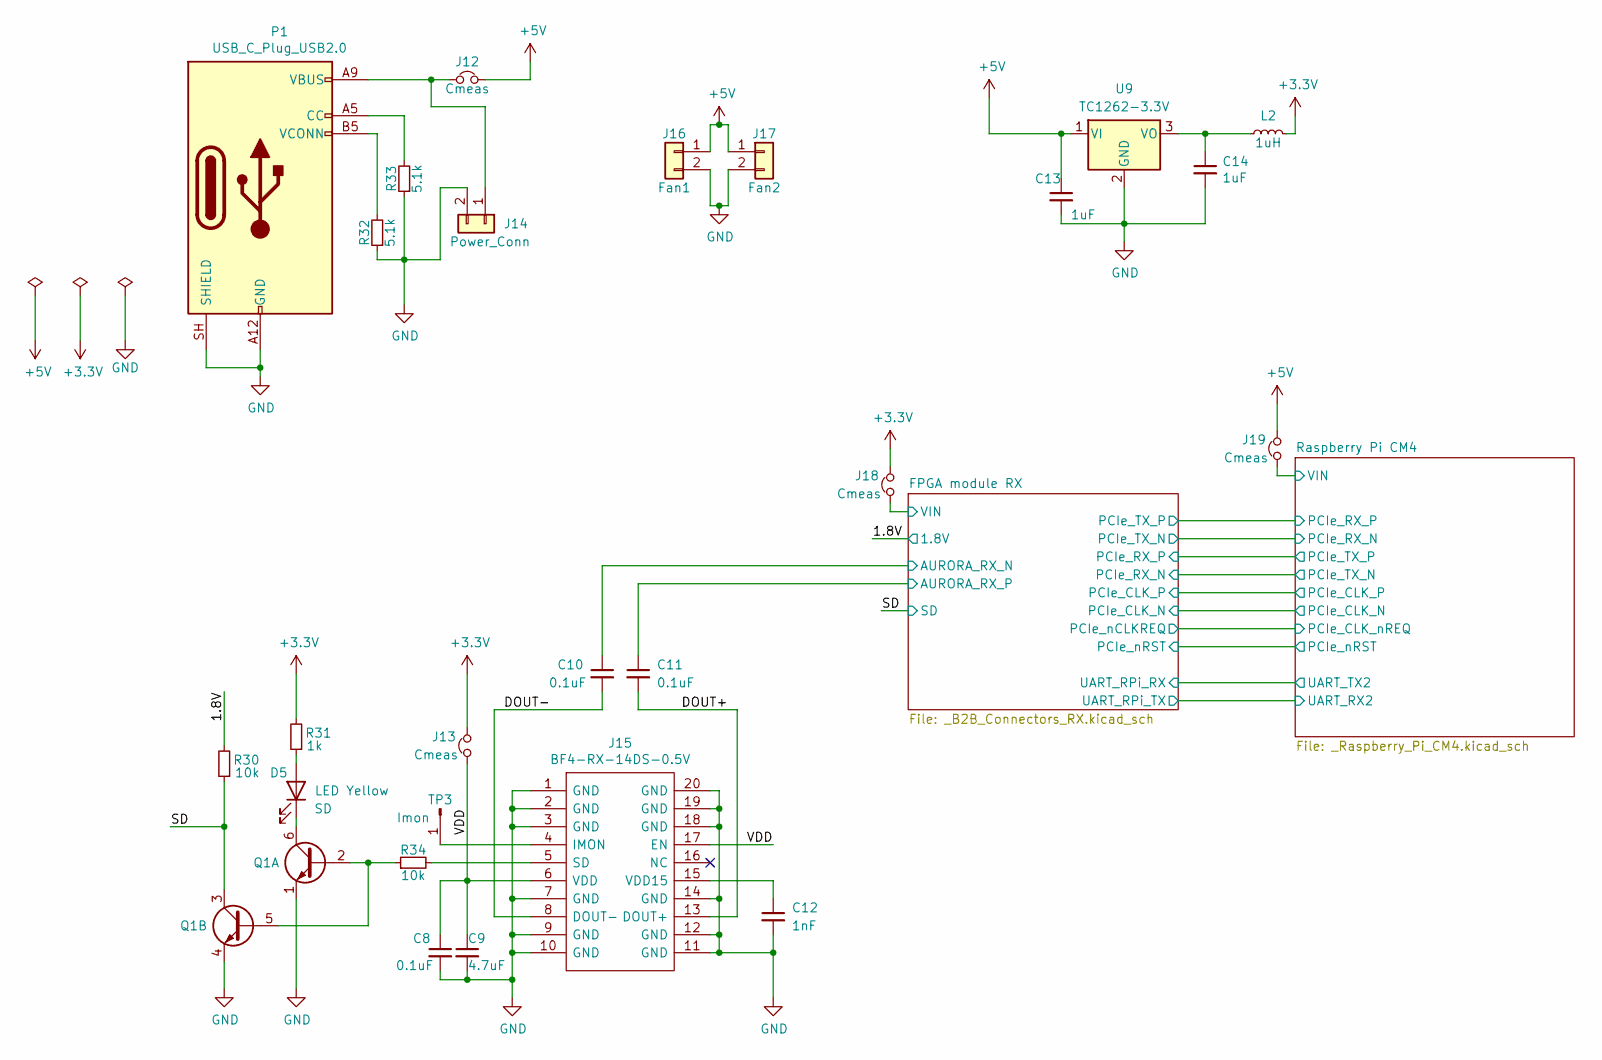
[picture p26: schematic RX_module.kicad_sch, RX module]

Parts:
C8, C10, C11: 0.1uF; C_0603_1608Metric_Pad1.08x0.95mm_HandSolder
C9: 4.7uF; C_0603_1608Metric_Pad1.08x0.95mm_HandSolder
C12: 1nF; C_0603_1608Metric_Pad1.08x0.95mm_HandSolder
C13, C14: 1uF; C_0603_1608Metric_Pad1.08x0.95mm_HandSolder
D5: LED Yellow; LED_0603_1608Metric_Pad1.05x0.95mm_HandSolder
J12, J13, J18, J19: Cmeas; PinHeader_1x02_P2.54mm_Vertical
J14: Power_Conn; JST_XH_B2B-XH-A_1x02_P2.50mm_Vertical
J15: BF4-RX-14DS-0.5V; BF4RX14DS05V
J16: Fan1; PinHeader_1x02_P2.54mm_Vertical
J17: Fan2; PinHeader_1x02_P2.54mm_Vertical
L2: 1uH; L_0603_1608Metric_Pad1.05x0.95mm_HandSolder
P1: USB_C_Plug_USB2.0; USB4125-GF-A
Q1: BC847BS; SOT-363_SC-70-6_Handsoldering
R30, R34: 10k; R_0603_1608Metric_Pad0.98x0.95mm_HandSolder
R31: 1k; R_0603_1608Metric_Pad0.98x0.95mm_HandSolder
R32, R33: 5.1k; R_0603_1608Metric_Pad0.98x0.95mm_HandSolder
TP3: Imon; TestPoint_Loop_D2.50mm_Drill1.0mm
U9: TC1262-3.3V; SOT-223-3_TabPin2

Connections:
+3V3: J13.2, J18.2, L2.2, R31.2
+5V: C13.1, J12.2, J16.1, J17.1, J19.2, U9.1 (VI)
/1.8V: R30.2; also elsewhere on the board
/DOUT+: C11.2, J15.13 (DOUT+)
/DOUT-: C10.2, J15.8 (DOUT-)
/FPGA module RX/AURORA_RX_N: C10.1; also elsewhere on the board
/FPGA module RX/AURORA_RX_P: C11.1; also elsewhere on the board
/FPGA module RX/VIN: J18.1; also elsewhere on the board
/Raspberry Pi CM4/VIN: J19.1; also elsewhere on the board
/SD: Q1.3 (C2), R30.1; also elsewhere on the board
/VDD: C8.1, C9.1, J13.1, J15.6 (VDD), J15.17 (EN)
GND: C8.2, C9.2, C12.2, C13.2, C14.2, J14.2, J15.1 (GND), J15.2 (GND), J15.3 (GND), J15.7 (GND), J15.9 (GND), J15.10 (GND), J15.11 (GND), J15.12 (GND), J15.14 (GND), J15.18 (GND), J15.19 (GND), J15.20 (GND), J16.2, J17.2, P1.A12 (GND), P1.B12 (GND), P1.SH (SHIELD), Q1.1 (E1), Q1.4 (E2), R32.1, R33.1, U9.2 (GND); also elsewhere on the board
unnamed: C12.1, J15.15 (VDD15)
unnamed: C14.1, L2.1, U9.3 (VO)
unnamed: D5.1 (K), Q1.6 (C1)
unnamed: D5.2 (A), R31.1
unnamed: J12.1, J14.1, P1.A9 (VBUS)
unnamed: J15.4 (IMON), TP3.1
unnamed: J15.5 (SD), R34.2
unnamed: P1.A5 (CC), R33.2
unnamed: P1.B5 (VCONN), R32.2
unnamed: Q1.2 (B1), Q1.5 (B2), R34.1

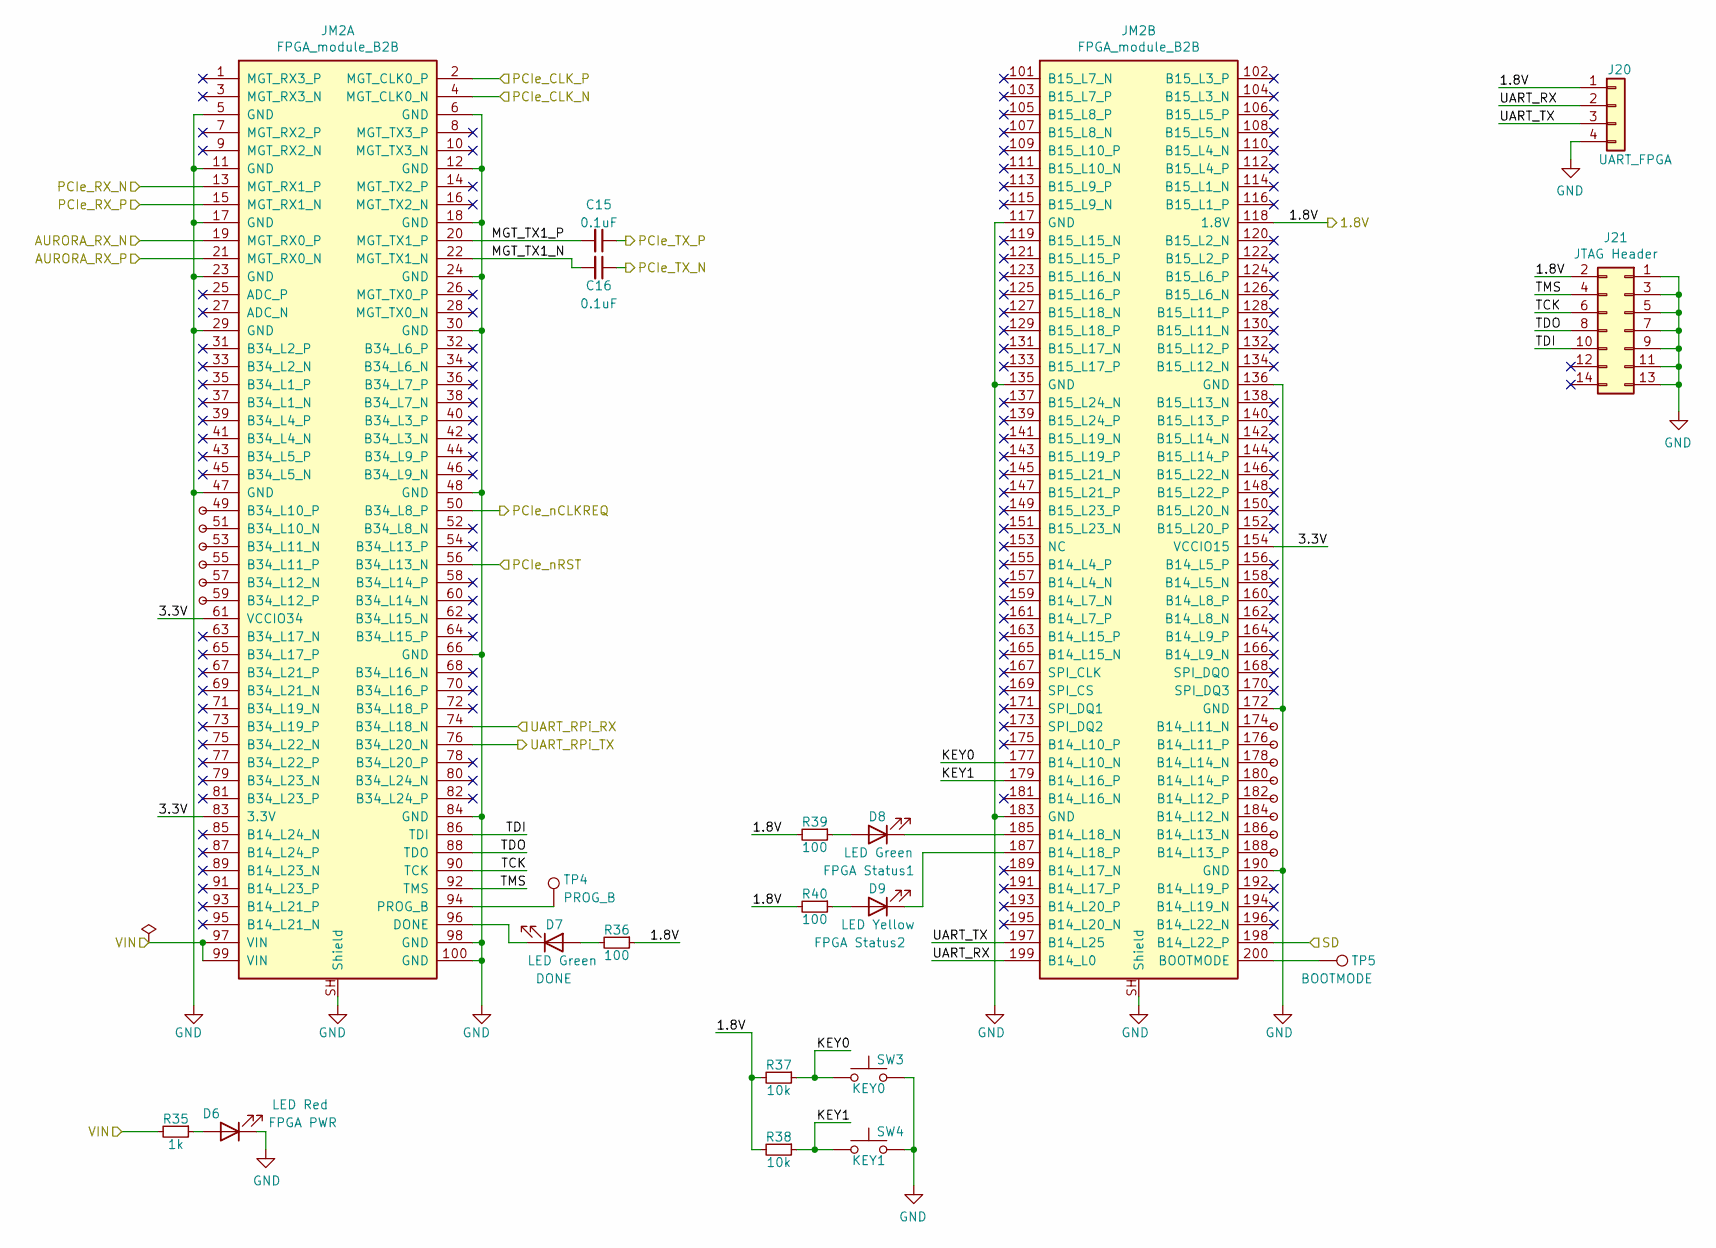
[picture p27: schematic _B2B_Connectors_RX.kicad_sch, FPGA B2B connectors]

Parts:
C15, C16: 0.1uF; C_0603_1608Metric_Pad1.08x0.95mm_HandSolder
D6: LED Red; LED_0603_1608Metric_Pad1.05x0.95mm_HandSolder
D7, D8: LED Green; LED_0603_1608Metric_Pad1.05x0.95mm_HandSolder
D9: LED Yellow; LED_0603_1608Metric_Pad1.05x0.95mm_HandSolder
J20: UART_FPGA; PinHeader_1x04_P2.54mm_Vertical
J21: JTAG Header; JTAG_Header
JM2: FPGA_module_B2B
P2, P3, P4, P5, P6, P7, P8, P9, P10, P11, P12, P13, P14, P15: ExtPad; ExtPoint_Pad_1.0x2.0mm
R35: 1k; R_0603_1608Metric_Pad0.98x0.95mm_HandSolder
R36, R39, R40: 100; R_0603_1608Metric_Pad0.98x0.95mm_HandSolder
R37, R38: 10k; R_0603_1608Metric_Pad0.98x0.95mm_HandSolder
SW3: KEY0; SW_SPST_PTS636
SW4: KEY1; SW_SPST_PTS636
TP4: PROG_B; TestPoint_Loop_D2.50mm_Drill1.0mm
TP5: BOOTMODE; TestPoint_Loop_D2.50mm_Drill1.0mm

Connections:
/1.8V: J20.1, J21.2, JM2.118 (1.8V), R36.1, R37.2, R38.2, R39.2, R40.2; also elsewhere on the board
/FPGA module RX/3.3V: JM2.61 (VCCIO34), JM2.83 (3.3V), JM2.154 (VCCIO15)
/FPGA module RX/AURORA_RX_N: JM2.19 (MGT_RX0_P); also elsewhere on the board
/FPGA module RX/AURORA_RX_P: JM2.21 (MGT_RX0_N); also elsewhere on the board
/FPGA module RX/KEY0: JM2.177 (B14_L10_N), R37.1, SW3.2
/FPGA module RX/KEY1: JM2.179 (B14_L16_P), R38.1, SW4.2
/FPGA module RX/MGT_TX1_N: C16.2, JM2.22 (MGT_TX1_N)
/FPGA module RX/MGT_TX1_P: C15.2, JM2.20 (MGT_TX1_P)
/FPGA module RX/PCIe_CLK_N: JM2.4 (MGT_CLK0_N); also elsewhere on the board
/FPGA module RX/PCIe_CLK_P: JM2.2 (MGT_CLK0_P); also elsewhere on the board
/FPGA module RX/PCIe_RX_N: JM2.13 (MGT_RX1_P); also elsewhere on the board
/FPGA module RX/PCIe_RX_P: JM2.15 (MGT_RX1_N); also elsewhere on the board
/FPGA module RX/PCIe_nRST: JM2.56 (B34_L13_N); also elsewhere on the board
/FPGA module RX/TCK: J21.6, JM2.90 (TCK)
/FPGA module RX/TDI: J21.10, JM2.86 (TDI)
/FPGA module RX/TDO: J21.8, JM2.88 (TDO)
/FPGA module RX/TMS: J21.4, JM2.92 (TMS)
/FPGA module RX/UART_RPi_RX: JM2.74 (B34_L18_N); also elsewhere on the board
/FPGA module RX/UART_RPi_TX: JM2.76 (B34_L20_N); also elsewhere on the board
/FPGA module RX/UART_RX: J20.2, JM2.199 (B14_L0)
/FPGA module RX/UART_TX: J20.3, JM2.197 (B14_L25)
/FPGA module RX/VIN: JM2.97 (VIN), JM2.99 (VIN), R35.2; also elsewhere on the board
/Raspberry Pi CM4/PCIe_CLK_nREQ: JM2.50 (B34_L8_P); also elsewhere on the board
/Raspberry Pi CM4/PCIe_RX_N: C16.1; also elsewhere on the board
/Raspberry Pi CM4/PCIe_RX_P: C15.1; also elsewhere on the board
/SD: JM2.198 (B14_L22_P); also elsewhere on the board
GND: D6.1 (K), J20.4, J21.1, J21.3, J21.5, J21.7, J21.9, J21.11, J21.13, JM2.5 (GND), JM2.6 (GND), JM2.11 (GND), JM2.12 (GND), JM2.17 (GND), JM2.18 (GND), JM2.23 (GND), JM2.24 (GND), JM2.29 (GND), JM2.30 (GND), JM2.47 (GND), JM2.48 (GND), JM2.66 (GND), JM2.84 (GND), JM2.98 (GND), JM2.100 (GND), JM2.117 (GND), JM2.135 (GND), JM2.136 (GND), JM2.172 (GND), JM2.183 (GND), JM2.190 (GND), JM2.SH (Shield), SW3.1, SW4.1; also elsewhere on the board
unnamed: D6.2 (A), R35.1
unnamed: D7.1 (K), JM2.96 (DONE)
unnamed: D7.2 (A), R36.2
unnamed: D8.1 (K), JM2.185 (B14_L18_N)
unnamed: D8.2 (A), R39.1
unnamed: D9.1 (K), JM2.187 (B14_L18_P)
unnamed: D9.2 (A), R40.1
unnamed: JM2.49 (B34_L10_P), P2.1
unnamed: JM2.51 (B34_L10_N), P3.1
unnamed: JM2.53 (B34_L11_N), P4.1
unnamed: JM2.55 (B34_L11_P), P5.1
unnamed: JM2.57 (B34_L12_N), P6.1
unnamed: JM2.59 (B34_L12_P), P7.1
unnamed: JM2.94 (PROG_B), TP4.1
unnamed: JM2.174 (B14_L11_N), P8.1
unnamed: JM2.176 (B14_L11_P), P9.1
unnamed: JM2.178 (B14_L14_N), P10.1
unnamed: JM2.180 (B14_L14_P), P11.1
unnamed: JM2.182 (B14_L12_P), P12.1
unnamed: JM2.184 (B14_L12_N), P13.1
unnamed: JM2.186 (B14_L13_N), P14.1
unnamed: JM2.188 (B14_L13_P), P15.1
unnamed: JM2.200 (BOOTMODE), TP5.1

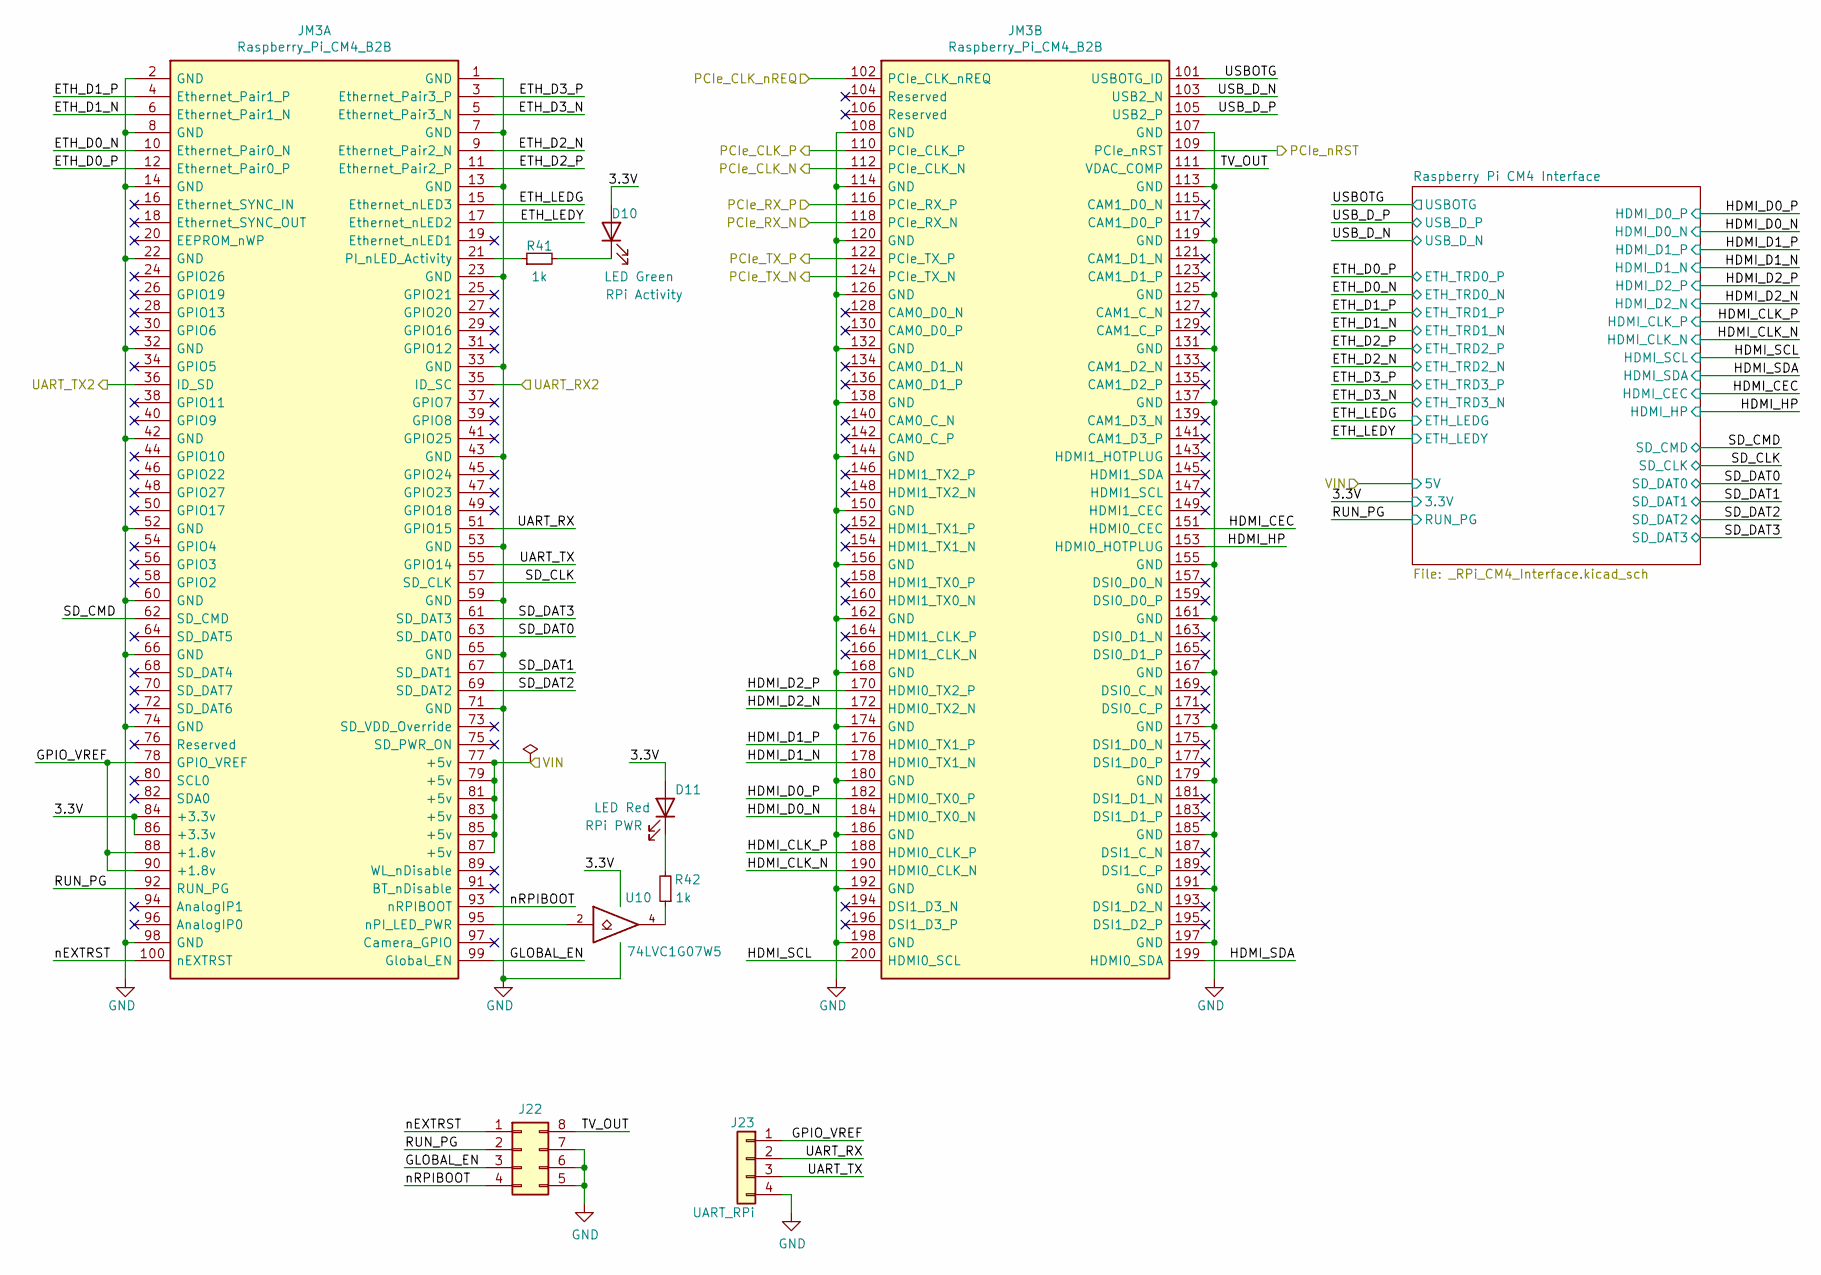
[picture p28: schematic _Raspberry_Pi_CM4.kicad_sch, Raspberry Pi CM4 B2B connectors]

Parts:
D10: LED Green; LED_0603_1608Metric_Pad1.05x0.95mm_HandSolder
D11: LED Red; LED_0603_1608Metric_Pad1.05x0.95mm_HandSolder
J22: RPi_CONFIG; PinHeader_2x04_P2.54mm_Vertical
J23: UART_RPi; PinHeader_1x04_P2.54mm_Vertical
JM3: Raspberry_Pi_CM4_B2B; Raspberry_Pi_Compute_Module_4
R41, R42: 1k; R_0603_1608Metric_Pad0.98x0.95mm_HandSolder
U10: 74LVC1G07W5; SOT-23-5_HandSoldering

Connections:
/FPGA module RX/PCIe_CLK_N: JM3.112 (PCIe_CLK_N); also elsewhere on the board
/FPGA module RX/PCIe_CLK_P: JM3.110 (PCIe_CLK_P); also elsewhere on the board
/FPGA module RX/PCIe_RX_N: JM3.124 (PCIe_TX_N); also elsewhere on the board
/FPGA module RX/PCIe_RX_P: JM3.122 (PCIe_TX_P); also elsewhere on the board
/FPGA module RX/PCIe_nRST: JM3.109 (PCIe_nRST); also elsewhere on the board
/FPGA module RX/UART_RPi_RX: JM3.36 (ID_SD); also elsewhere on the board
/FPGA module RX/UART_RPi_TX: JM3.35 (ID_SC); also elsewhere on the board
/Raspberry Pi CM4/ETH_D0_N: JM3.10 (Ethernet_Pair0_N); also elsewhere on the board
/Raspberry Pi CM4/ETH_D0_P: JM3.12 (Ethernet_Pair0_P); also elsewhere on the board
/Raspberry Pi CM4/ETH_D1_N: JM3.6 (Ethernet_Pair1_N); also elsewhere on the board
/Raspberry Pi CM4/ETH_D1_P: JM3.4 (Ethernet_Pair1_P); also elsewhere on the board
/Raspberry Pi CM4/ETH_D2_N: JM3.9 (Ethernet_Pair2_N); also elsewhere on the board
/Raspberry Pi CM4/ETH_D2_P: JM3.11 (Ethernet_Pair2_P); also elsewhere on the board
/Raspberry Pi CM4/ETH_D3_N: JM3.5 (Ethernet_Pair3_N); also elsewhere on the board
/Raspberry Pi CM4/ETH_D3_P: JM3.3 (Ethernet_Pair3_P); also elsewhere on the board
/Raspberry Pi CM4/ETH_LEDG: JM3.15 (Ethernet_nLED3); also elsewhere on the board
/Raspberry Pi CM4/ETH_LEDY: JM3.17 (Ethernet_nLED2); also elsewhere on the board
/Raspberry Pi CM4/GLOBAL_EN: J22.3, JM3.99 (Global_EN)
/Raspberry Pi CM4/GPIO_VREF: J23.1, JM3.78 (GPIO_VREF), JM3.88 (+1.8v), JM3.90 (+1.8v)
/Raspberry Pi CM4/HDMI_CEC: JM3.151 (HDMI0_CEC); also elsewhere on the board
/Raspberry Pi CM4/HDMI_CLK_N: JM3.190 (HDMI0_CLK_N); also elsewhere on the board
/Raspberry Pi CM4/HDMI_CLK_P: JM3.188 (HDMI0_CLK_P); also elsewhere on the board
/Raspberry Pi CM4/HDMI_D0_N: JM3.184 (HDMI0_TX0_N); also elsewhere on the board
/Raspberry Pi CM4/HDMI_D0_P: JM3.182 (HDMI0_TX0_P); also elsewhere on the board
/Raspberry Pi CM4/HDMI_D1_N: JM3.178 (HDMI0_TX1_N); also elsewhere on the board
/Raspberry Pi CM4/HDMI_D1_P: JM3.176 (HDMI0_TX1_P); also elsewhere on the board
/Raspberry Pi CM4/HDMI_D2_N: JM3.172 (HDMI0_TX2_N); also elsewhere on the board
/Raspberry Pi CM4/HDMI_D2_P: JM3.170 (HDMI0_TX2_P); also elsewhere on the board
/Raspberry Pi CM4/HDMI_HP: JM3.153 (HDMI0_HOTPLUG); also elsewhere on the board
/Raspberry Pi CM4/HDMI_SCL: JM3.200 (HDMI0_SCL); also elsewhere on the board
/Raspberry Pi CM4/HDMI_SDA: JM3.199 (HDMI0_SDA); also elsewhere on the board
/Raspberry Pi CM4/PCIe_CLK_nREQ: JM3.102 (PCIe_CLK_nREQ); also elsewhere on the board
/Raspberry Pi CM4/PCIe_RX_N: JM3.118 (PCIe_RX_N); also elsewhere on the board
/Raspberry Pi CM4/PCIe_RX_P: JM3.116 (PCIe_RX_P); also elsewhere on the board
/Raspberry Pi CM4/RUN_PG: J22.2, JM3.92 (RUN_PG); also elsewhere on the board
/Raspberry Pi CM4/SD_CLK: JM3.57 (SD_CLK); also elsewhere on the board
/Raspberry Pi CM4/SD_CMD: JM3.62 (SD_CMD); also elsewhere on the board
/Raspberry Pi CM4/SD_DAT0: JM3.63 (SD_DAT0); also elsewhere on the board
/Raspberry Pi CM4/SD_DAT1: JM3.67 (SD_DAT1); also elsewhere on the board
/Raspberry Pi CM4/SD_DAT2: JM3.69 (SD_DAT2); also elsewhere on the board
/Raspberry Pi CM4/SD_DAT3: JM3.61 (SD_DAT3); also elsewhere on the board
/Raspberry Pi CM4/TV_OUT: J22.8, JM3.111 (VDAC_COMP)
/Raspberry Pi CM4/UART_RX: J23.2, JM3.51 (GPIO15)
/Raspberry Pi CM4/UART_TX: J23.3, JM3.55 (GPIO14)
/Raspberry Pi CM4/USBOTG: JM3.101 (USBOTG_ID); also elsewhere on the board
/Raspberry Pi CM4/USB_D_N: JM3.103 (USB2_N); also elsewhere on the board
/Raspberry Pi CM4/USB_D_P: JM3.105 (USB2_P); also elsewhere on the board
/Raspberry Pi CM4/VIN: JM3.77 (+5v), JM3.79 (+5v), JM3.81 (+5v), JM3.83 (+5v), JM3.85 (+5v), JM3.87 (+5v); also elsewhere on the board
/Raspberry Pi CM4/nEXTRST: J22.1, JM3.100 (nEXTRST)
/Raspberry Pi CM4/nRPIBOOT: J22.4, JM3.93 (nRPIBOOT)
GND: J22.5, J22.6, J22.7, J23.4, JM3.1 (GND), JM3.2 (GND), JM3.7 (GND), JM3.8 (GND), JM3.13 (GND), JM3.14 (GND), JM3.22 (GND), JM3.23 (GND), JM3.32 (GND), JM3.33 (GND), JM3.42 (GND), JM3.43 (GND), JM3.52 (GND), JM3.53 (GND), JM3.59 (GND), JM3.60 (GND), JM3.65 (GND), JM3.66 (GND), JM3.71 (GND), JM3.74 (GND), JM3.98 (GND), JM3.107 (GND), JM3.108 (GND), JM3.113 (GND), JM3.114 (GND), JM3.119 (GND), JM3.120 (GND), JM3.125 (GND), JM3.126 (GND), JM3.131 (GND), JM3.132 (GND), JM3.137 (GND), JM3.138 (GND), JM3.144 (GND), JM3.150 (GND), JM3.155 (GND), JM3.156 (GND), JM3.161 (GND), JM3.162 (GND), JM3.167 (GND), JM3.168 (GND), JM3.173 (GND), JM3.174 (GND), JM3.179 (GND), JM3.180 (GND), JM3.185 (GND), JM3.186 (GND), JM3.191 (GND), JM3.192 (GND), JM3.197 (GND), JM3.198 (GND), U10.3 (GND); also elsewhere on the board
unnamed: D10.1 (K), R41.2
unnamed: D11.1 (K), R42.2
unnamed: JM3.21 (PI_nLED_Activity), R41.1
unnamed: JM3.95 (nPI_LED_PWR), U10.2
unnamed: R42.1, U10.4
VCC: D10.2 (A), D11.2 (A), JM3.84 (+3.3v), JM3.86 (+3.3v), U10.5 (VCC); also elsewhere on the board

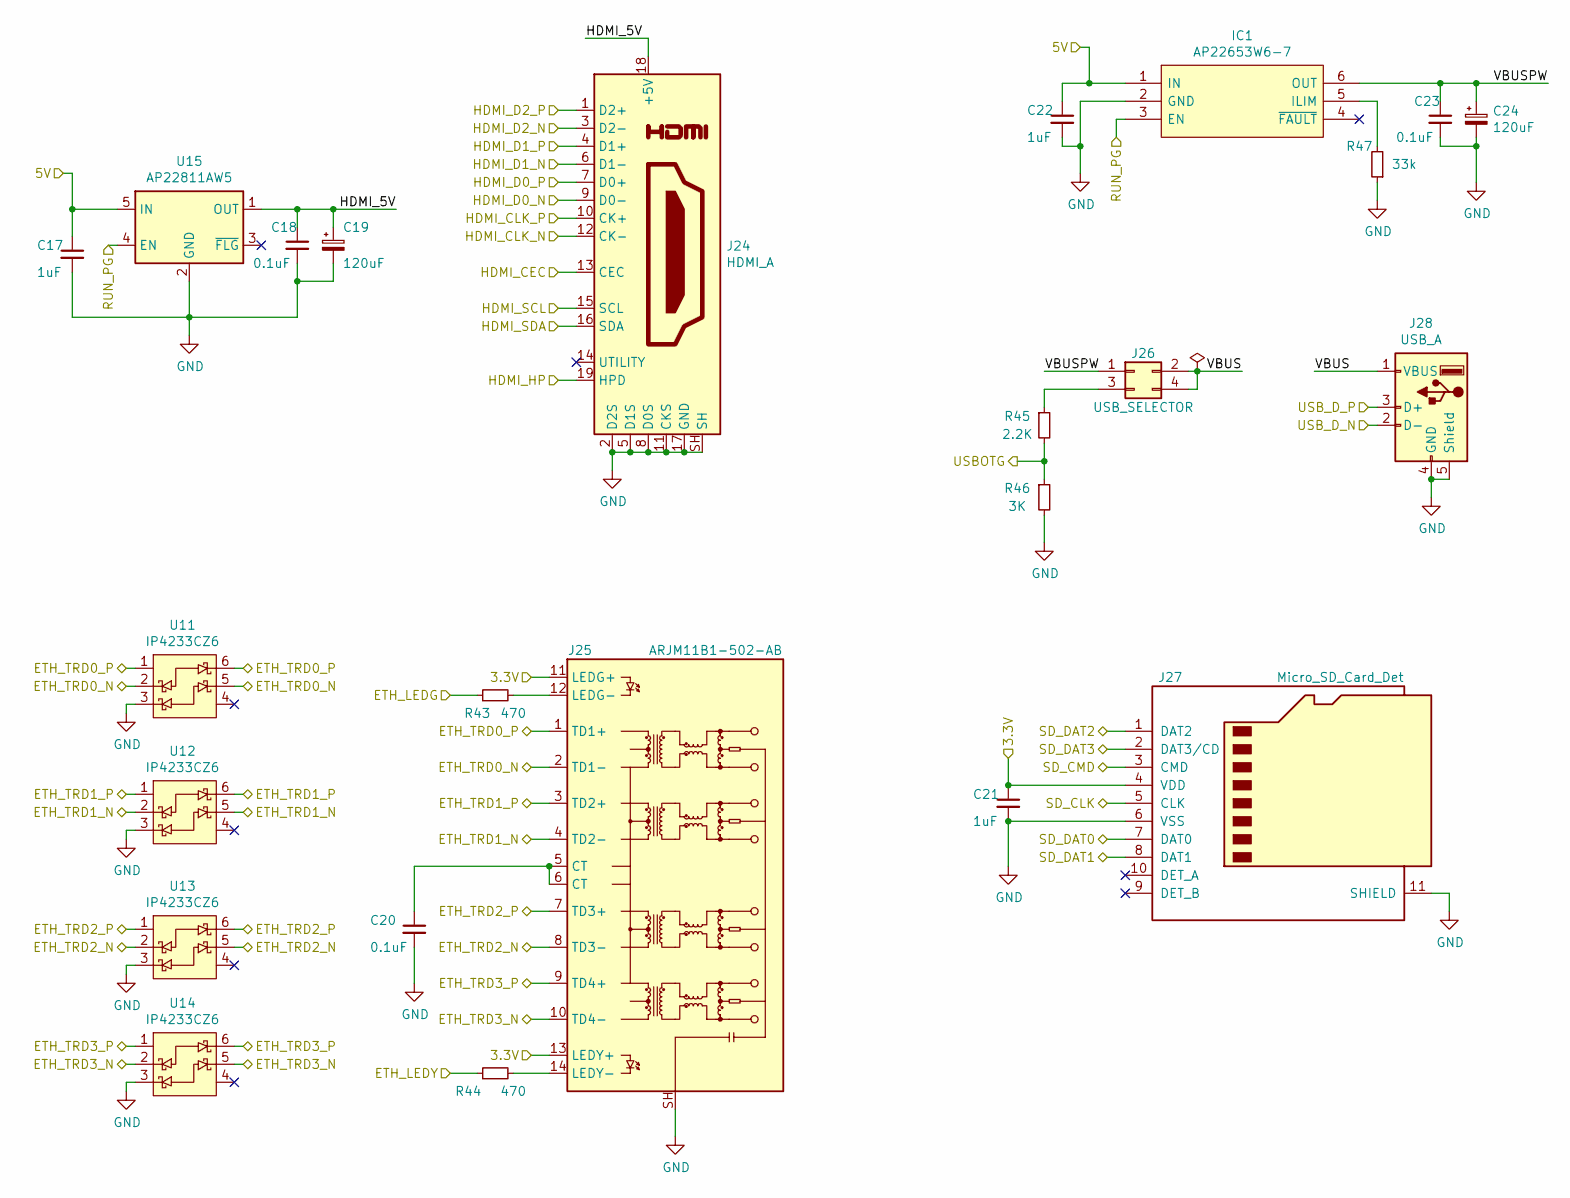
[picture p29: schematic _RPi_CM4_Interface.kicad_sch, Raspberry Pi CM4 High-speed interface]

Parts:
C17, C21, C22: 1uF; C_0603_1608Metric_Pad1.08x0.95mm_HandSolder
C18, C20, C23: 0.1uF; C_0603_1608Metric_Pad1.08x0.95mm_HandSolder
C19, C24: 120uF; CP_Radial_D6.3mm_P2.50mm
IC1: AP22653W6-7; SOT-23-6_Handsoldering
J24: HDMI_A; SS-53000-001
J25: ARJM11B1-502-AB; ARJM11B1-502-AB-ER2
J26: USB_SELECTOR; PinHeader_2x02_P2.54mm_Vertical
J27: Micro_SD_Card_Det; Molex_1051620001
J28: USB_A; USB_A_Stewart_SS-52100-001_Horizontal
R43, R44: 470; R_0603_1608Metric_Pad0.98x0.95mm_HandSolder
R45: 2.2K; R_0603_1608Metric_Pad0.98x0.95mm_HandSolder
R46: 3K; R_0603_1608Metric_Pad0.98x0.95mm_HandSolder
R47: 33k; R_0603_1608Metric_Pad0.98x0.95mm_HandSolder
U11, U12, U13, U14: IP4233CZ6; SOT-363_SC-70-6_Handsoldering
U15: AP22811AW5; SOT-23-5_HandSoldering

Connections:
/Raspberry Pi CM4/ETH_D0_N: J25.2 (TD1-), U11.2 (C1), U11.5 (C2); also elsewhere on the board
/Raspberry Pi CM4/ETH_D0_P: J25.1 (TD1+), U11.1, U11.6 (C1); also elsewhere on the board
/Raspberry Pi CM4/ETH_D1_N: J25.4 (TD2-), U12.2 (C1), U12.5 (C2); also elsewhere on the board
/Raspberry Pi CM4/ETH_D1_P: J25.3 (TD2+), U12.1, U12.6 (C1); also elsewhere on the board
/Raspberry Pi CM4/ETH_D2_N: J25.8 (TD3-), U13.2 (C1), U13.5 (C2); also elsewhere on the board
/Raspberry Pi CM4/ETH_D2_P: J25.7 (TD3+), U13.1, U13.6 (C1); also elsewhere on the board
/Raspberry Pi CM4/ETH_D3_N: J25.10 (TD4-), U14.2 (C1), U14.5 (C2); also elsewhere on the board
/Raspberry Pi CM4/ETH_D3_P: J25.9 (TD4+), U14.1, U14.6 (C1); also elsewhere on the board
/Raspberry Pi CM4/ETH_LEDG: R43.1; also elsewhere on the board
/Raspberry Pi CM4/ETH_LEDY: R44.1; also elsewhere on the board
/Raspberry Pi CM4/HDMI_CEC: J24.13 (CEC); also elsewhere on the board
/Raspberry Pi CM4/HDMI_CLK_N: J24.12 (CK-); also elsewhere on the board
/Raspberry Pi CM4/HDMI_CLK_P: J24.10 (CK+); also elsewhere on the board
/Raspberry Pi CM4/HDMI_D0_N: J24.9 (D0-); also elsewhere on the board
/Raspberry Pi CM4/HDMI_D0_P: J24.7 (D0+); also elsewhere on the board
/Raspberry Pi CM4/HDMI_D1_N: J24.6 (D1-); also elsewhere on the board
/Raspberry Pi CM4/HDMI_D1_P: J24.4 (D1+); also elsewhere on the board
/Raspberry Pi CM4/HDMI_D2_N: J24.3 (D2-); also elsewhere on the board
/Raspberry Pi CM4/HDMI_D2_P: J24.1 (D2+); also elsewhere on the board
/Raspberry Pi CM4/HDMI_HP: J24.19 (HPD); also elsewhere on the board
/Raspberry Pi CM4/HDMI_SCL: J24.15 (SCL); also elsewhere on the board
/Raspberry Pi CM4/HDMI_SDA: J24.16 (SDA); also elsewhere on the board
/Raspberry Pi CM4/RUN_PG: IC1.3 (EN), U15.4 (EN); also elsewhere on the board
/Raspberry Pi CM4/Raspberry Pi CM4 Interface/HDMI_5V: C18.1, C19.1, J24.18 (+5V), U15.1 (OUT)
/Raspberry Pi CM4/Raspberry Pi CM4 Interface/VBUS: J26.2, J26.4, J28.1 (VBUS)
/Raspberry Pi CM4/Raspberry Pi CM4 Interface/VBUSPW: C23.1, C24.1, IC1.6 (OUT), J26.1
/Raspberry Pi CM4/SD_CLK: J27.5 (CLK); also elsewhere on the board
/Raspberry Pi CM4/SD_CMD: J27.3 (CMD); also elsewhere on the board
/Raspberry Pi CM4/SD_DAT0: J27.7 (DAT0); also elsewhere on the board
/Raspberry Pi CM4/SD_DAT1: J27.8 (DAT1); also elsewhere on the board
/Raspberry Pi CM4/SD_DAT2: J27.1 (DAT2); also elsewhere on the board
/Raspberry Pi CM4/SD_DAT3: J27.2 (DAT3/CD); also elsewhere on the board
/Raspberry Pi CM4/USBOTG: R45.2, R46.1; also elsewhere on the board
/Raspberry Pi CM4/USB_D_N: J28.2 (D-); also elsewhere on the board
/Raspberry Pi CM4/USB_D_P: J28.3 (D+); also elsewhere on the board
/Raspberry Pi CM4/VIN: C17.1, C22.1, IC1.1 (IN), U15.5 (IN); also elsewhere on the board
GND: C17.2, C18.2, C19.2, C20.2, C21.2, C22.2, C23.2, C24.2, IC1.2 (GND), J24.2 (D2S), J24.5 (D1S), J24.8 (D0S), J24.11 (CKS), J24.17 (GND), J24.SH, J25.SH, J27.6 (VSS), J27.11 (SHIELD), J28.4 (GND), J28.5 (Shield), R46.2, R47.1, U11.3 (C2), U12.3 (C2), U13.3 (C2), U14.3 (C2), U15.2 (GND); also elsewhere on the board
unnamed: C20.1, J25.5 (CT), J25.6 (CT)
unnamed: IC1.5 (ILIM), R47.2
unnamed: J25.12 (LEDG-), R43.2
unnamed: J25.14 (LEDY-), R44.2
unnamed: J26.3, R45.1
VCC: C21.1, J25.11 (LEDG+), J25.13 (LEDY+), J27.4 (VDD); also elsewhere on the board

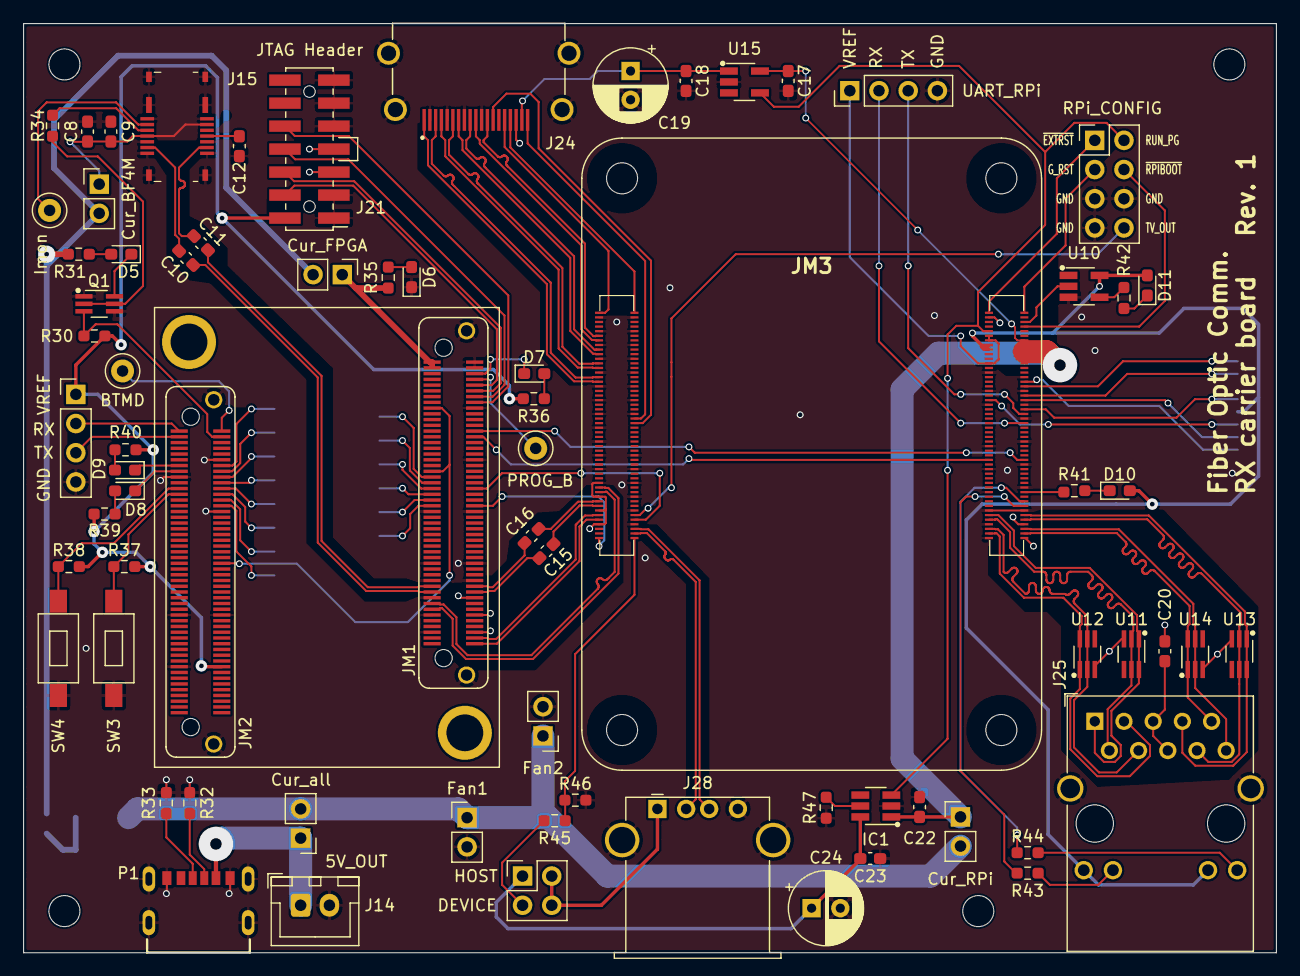
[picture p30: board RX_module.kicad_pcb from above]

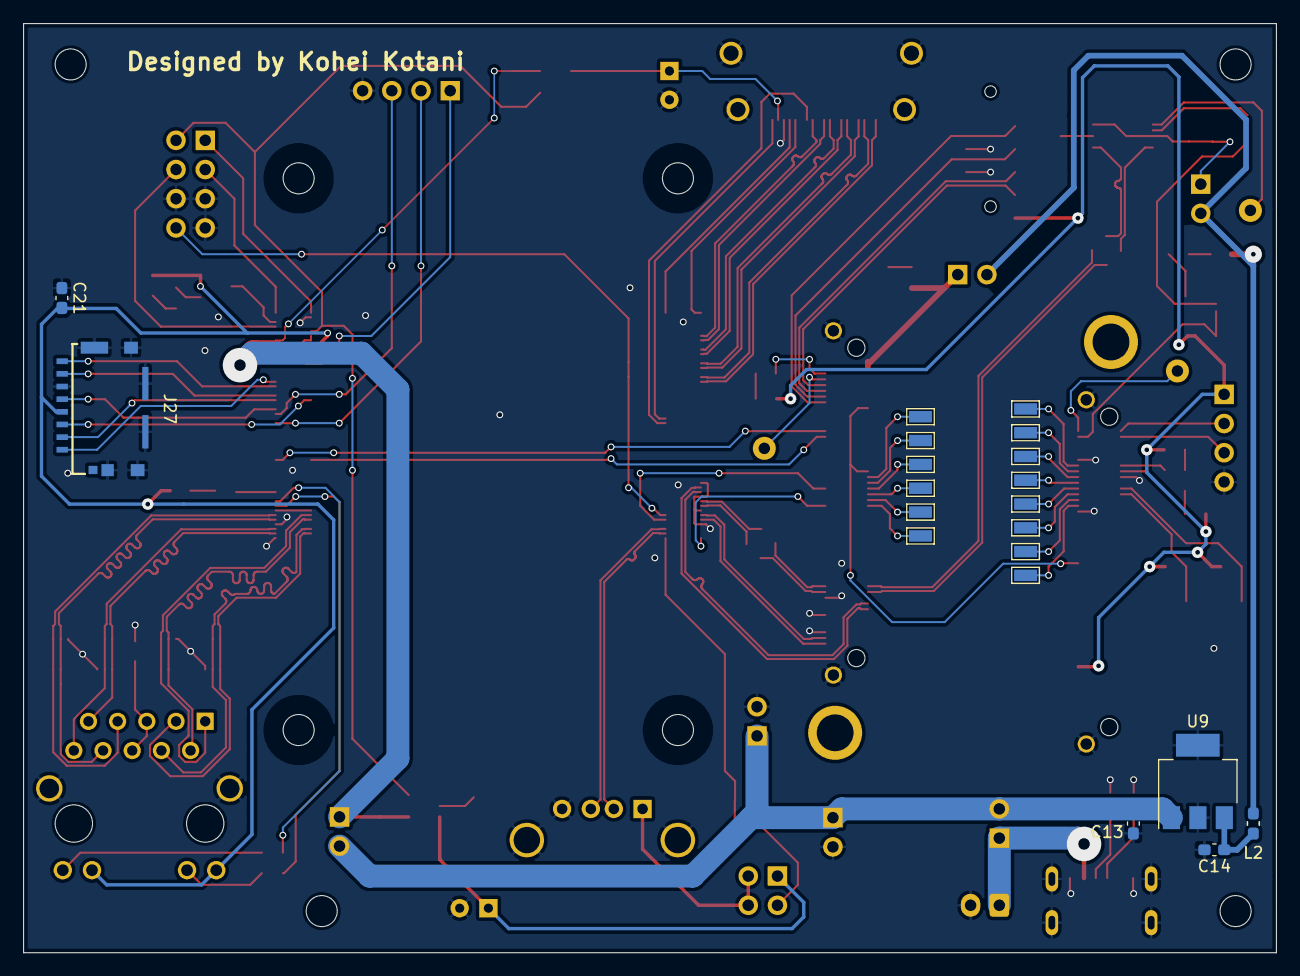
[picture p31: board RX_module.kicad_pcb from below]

Board: 2 copper layers, 109.0 x 80.8 mm, 91 parts (20 on the bottom side), 119 nets.

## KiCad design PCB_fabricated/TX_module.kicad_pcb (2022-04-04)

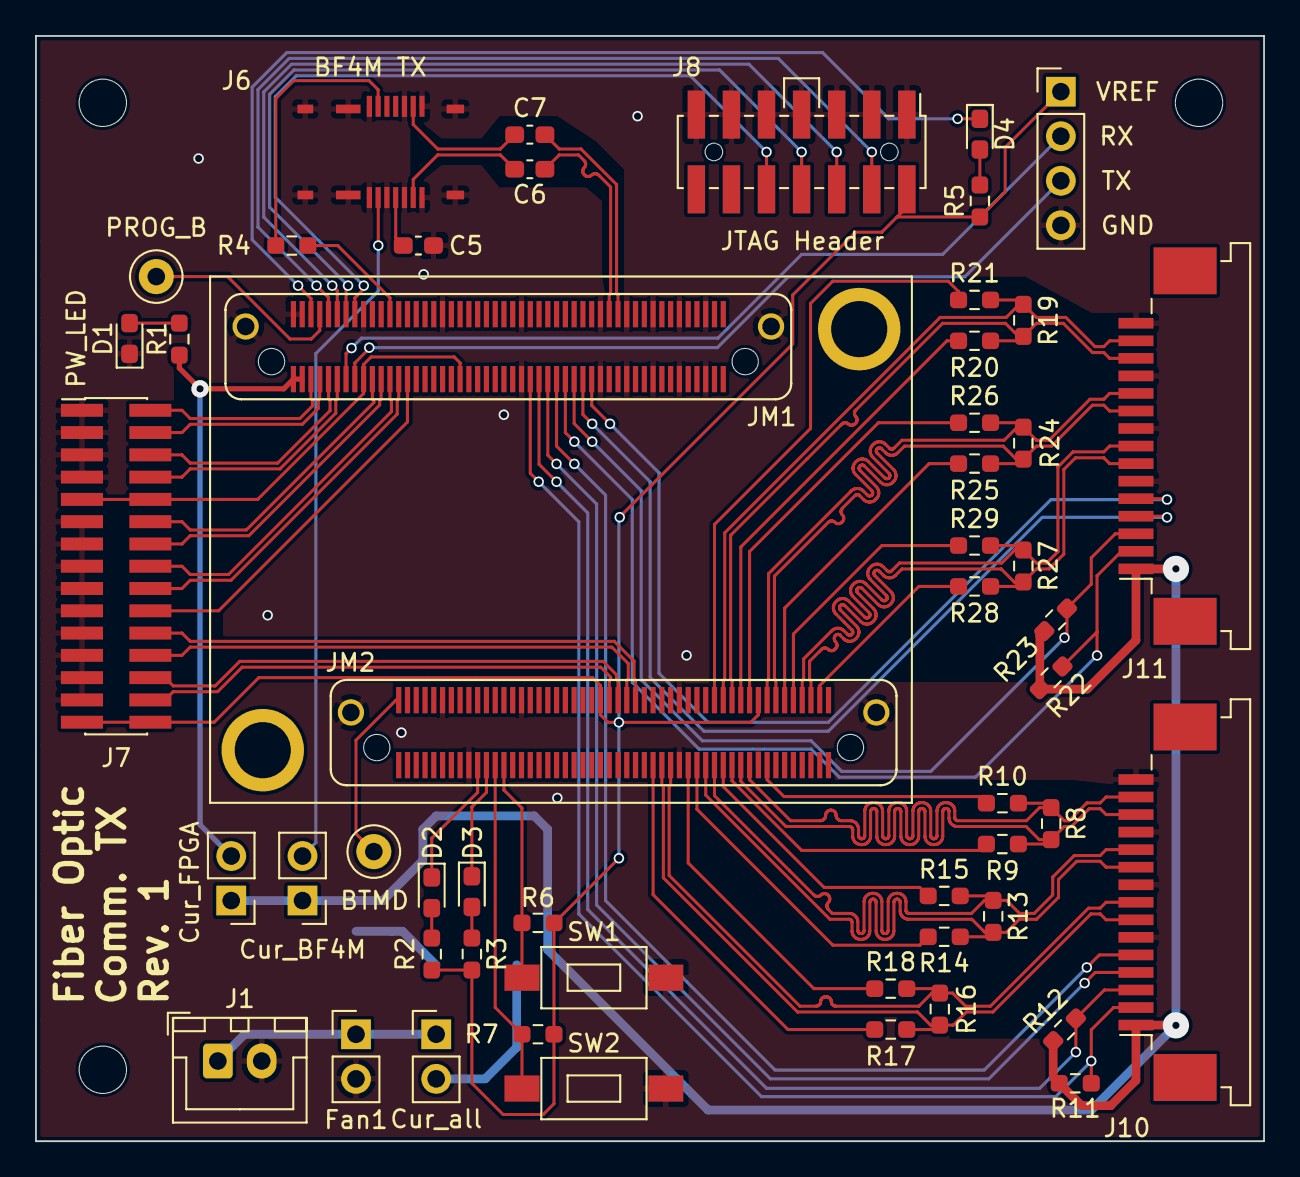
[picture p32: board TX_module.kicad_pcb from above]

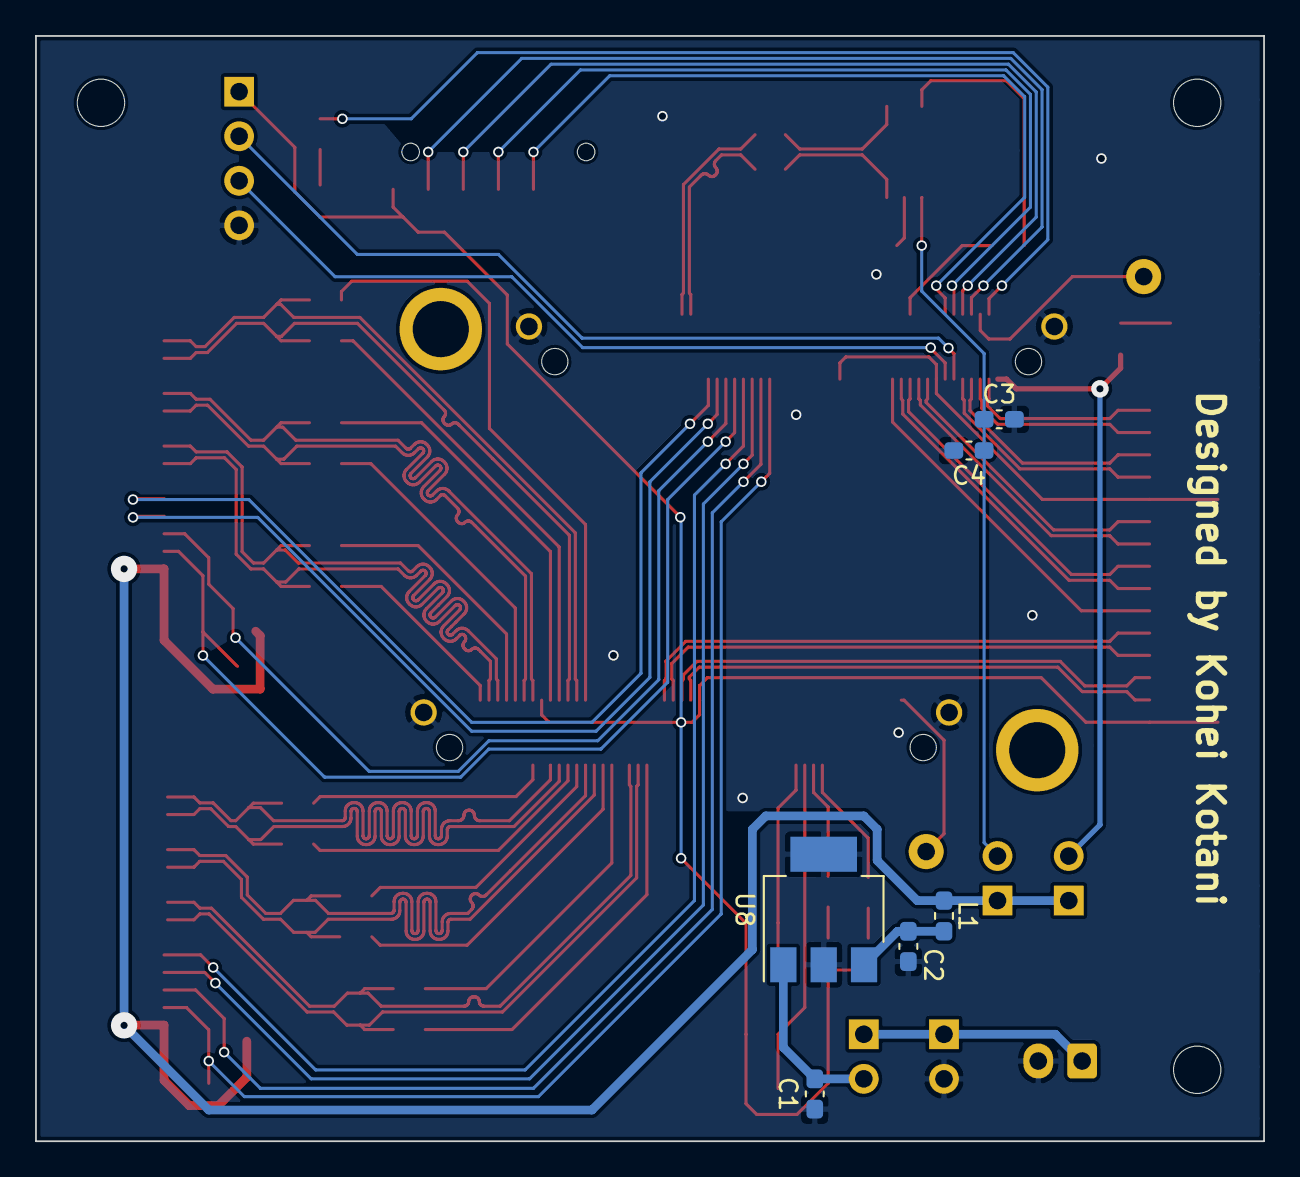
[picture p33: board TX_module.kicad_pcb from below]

Board: 2 copper layers, 70.0 x 63.0 mm, 58 parts (6 on the bottom side), 78 nets.

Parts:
C1, C2: 1uF; C_0603_1608Metric_Pad1.08x0.95mm_HandSolder
C3, C6, C7: 0.1uF; C_0603_1608Metric_Pad1.08x0.95mm_HandSolder
C4: 4.7uF; C_0603_1608Metric_Pad1.08x0.95mm_HandSolder
C5: 0.01uF; C_0603_1608Metric_Pad1.08x0.95mm_HandSolder
D1: LED Red; LED_0603_1608Metric_Pad1.05x0.95mm_HandSolder
D2, D4: LED Green; LED_0603_1608Metric_Pad1.05x0.95mm_HandSolder
D3: LED Yellow; LED_0603_1608Metric_Pad1.05x0.95mm_HandSolder
J1: Power_Conn; JST_XH_B2B-XH-A_1x02_P2.50mm_Vertical
J2: Fan1; PinHeader_1x02_P2.54mm_Vertical
J3, J4, J5: Cmeas; PinHeader_1x02_P2.54mm_Vertical
J6: BF4-TX-14DS-0.5V; BF4TX14DS05V
J7: Conn_02x15_Odd_Even; PinHeader_2x15_P1.27mm_Vertical_SMD
J8: JTAG Header; JTAG_Header
J9: UART_FPGA; PinHeader_1x04_P2.54mm_Vertical
J10, J11: FFC connector; TE_1-84953-5_1x15-1MP_P1.0mm_Horizontal
JM1: FPGA_module_B2B
L1: 1uH; L_0603_1608Metric_Pad1.05x0.95mm_HandSolder
R1: 1k; R_0603_1608Metric_Pad0.98x0.95mm_HandSolder
R2, R3, R5, R9, R10, R14, R15, R17, R18, R20, R21, R25, R26, R28, R29: 100; R_0603_1608Metric_Pad0.98x0.95mm_HandSolder
R4: 4.7k; R_0603_1608Metric_Pad0.98x0.95mm_HandSolder
R6, R7: 10k; R_0603_1608Metric_Pad0.98x0.95mm_HandSolder
R8, R13, R16, R19, R24, R27: 150; R_0603_1608Metric_Pad0.98x0.95mm_HandSolder
R11, R12, R22, R23: 1.5K; R_0603_1608Metric_Pad0.98x0.95mm_HandSolder
SW1: KEY0; SW_SPST_PTS636
SW2: KEY1; SW_SPST_PTS636
TP1: PROG_B; TestPoint_Loop_D2.50mm_Drill1.0mm
TP2: BOOTMODE; TestPoint_Loop_D2.50mm_Drill1.0mm
U8: TC1262-3.3V; SOT-223-3_TabPin2

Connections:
+3V3: J4.1, J5.1, J10.1, J11.1, L1.2, R11.2, R12.2, R22.2, R23.2
+5V: J1.1, J2.1, J3.1
/BF4M_EN: J6.17, R4.1
/DIN+: C6.2, J6.8
/DIN-: C7.2, J6.13
/FPGA module TX/1.8V: J7.29, J7.30, J8.2, J9.1, JM1.118, JM1.154, R2.2, R3.2, R5.1, R6.2, R7.2
/FPGA module TX/3.3V: J7.9, J7.10, JM1.61, JM1.83
/FPGA module TX/AURORA_TX_N: C7.1, JM1.26
/FPGA module TX/AURORA_TX_P: C6.1, JM1.28
/FPGA module TX/B14_L21_N: J7.2, JM1.95
/FPGA module TX/B14_L21_P: J7.4, JM1.93
/FPGA module TX/B14_L23_N: J7.8, JM1.89
/FPGA module TX/B14_L23_P: J7.6, JM1.91
/FPGA module TX/B15_L20_N: J7.26, JM1.150
/FPGA module TX/B15_L20_P: J7.28, JM1.152
/FPGA module TX/B15_L22_N: J7.22, JM1.146
/FPGA module TX/B15_L22_P: J7.24, JM1.148
/FPGA module TX/B34_L19_P: J7.20, JM1.73
/FPGA module TX/B34_L22_N: J7.18, JM1.75
/FPGA module TX/B34_L22_P: J7.16, JM1.77
/FPGA module TX/B34_L23_N: J7.14, JM1.79
/FPGA module TX/B34_L23_P: J7.12, JM1.81
/FPGA module TX/KEY0: JM1.175, R6.1, SW1.1
/FPGA module TX/KEY1: JM1.177, R7.1, SW2.1
/FPGA module TX/LED0: D2.1, JM1.181
/FPGA module TX/LED1: D3.1, JM1.179
/FPGA module TX/TCK: J8.6, JM1.90
/FPGA module TX/TDI: J8.10, JM1.86
/FPGA module TX/TDO: J8.8, JM1.88
/FPGA module TX/TMS: J8.4, JM1.92
/FPGA module TX/UART_RX: J9.2, JM1.87
/FPGA module TX/UART_TX: J9.3, JM1.85
/FPGA module TX/VIN: J4.2, JM1.97, JM1.99, R1.2
/a6: JM1.123, R9.1
/a7: JM1.115, R10.1
/a8: JM1.131, R14.1
/a9: JM1.125, R15.1
/a10: JM1.141, R17.1
/a11: JM1.133, R18.1
/a12: J10.4, JM1.41
/a13: J10.3, JM1.43, R12.1
/a14: J10.2, JM1.45, R11.1
/a15: J10.5, JM1.39
/b6: JM1.122, R20.1
/b7: JM1.128, R21.1
/b8: JM1.112, R25.1
/b9: JM1.120, R26.1
/b10: JM1.104, R28.1
/b11: JM1.110, R29.1
/b12: J11.4, JM1.33
/b13: J11.3, JM1.35, R23.1
/b14: J11.2, JM1.37, R22.1
/b15: J11.5, JM1.31
GND: C1.2, C2.2, C3.2, C4.2, C5.2, D1.1, J1.2, J2.2, J6.1, J6.2, J6.3, J6.5, J6.7, J6.9, J6.10, J6.11, J6.12, J6.14, J6.18, J6.19, J6.20, J7.1, J7.3, J7.5, J7.7, J7.11, J7.13, J7.15, J7.17, J7.19, J7.21, J7.23, J7.25, J7.27, J8.1, J8.3, J8.5, J8.7, J8.9, J8.11, J8.13, J9.4, J10.6, J10.9, J10.12, J10.15, J11.6, J11.9, J11.12, J11.15, JM1.5, JM1.6, JM1.11, JM1.12, JM1.17, JM1.18, JM1.23, JM1.24, JM1.29, JM1.30, JM1.47, JM1.48, JM1.66, JM1.84, JM1.98, JM1.100, JM1.117, JM1.135, JM1.136, JM1.172, JM1.183, JM1.190, JM1.SH, SW1.2, SW2.2, U8.2
MIPI1_CLK_N: J10.8, JM1.137, R16.1, R18.2
MIPI1_CLK_P: J10.7, JM1.139, R16.2, R17.2
MIPI1_LANE0_N: J10.14, JM1.119, R8.1, R10.2
MIPI1_LANE0_P: J10.13, JM1.121, R8.2, R9.2
MIPI1_LANE1_N: J10.11, JM1.127, R13.1, R15.2
MIPI1_LANE1_P: J10.10, JM1.129, R13.2, R14.2
MIPI2_CLK_N: J11.8, JM1.108, R27.1, R29.2
MIPI2_CLK_P: J11.7, JM1.106, R27.2, R28.2
MIPI2_LANE0_N: J11.14, JM1.126, R19.1, R21.2
MIPI2_LANE0_P: J11.13, JM1.124, R19.2, R20.2
MIPI2_LANE1_N: J11.11, JM1.116, R24.1, R26.2
MIPI2_LANE1_P: J11.10, JM1.114, R24.2, R25.2
unnamed: C1.1, J3.2, U8.1
unnamed: C2.1, L1.1, U8.3
unnamed: C3.1, C4.1, J5.2, J6.4
unnamed: C5.1, J6.6
unnamed: D1.2, R1.1
unnamed: D2.2, R2.1
unnamed: D3.2, R3.1
unnamed: D4.1, JM1.96
unnamed: D4.2, R5.2
unnamed: JM1.78, R4.2
unnamed: JM1.94, TP1.1
unnamed: JM1.200, TP2.1

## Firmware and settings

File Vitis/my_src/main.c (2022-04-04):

#include <stdio.h>
#include "platform.h"
#include "xil_printf.h"
#include "xstatus.h"
#include "sleep.h"
#include "xiic.h"
#include "xgpio.h"
#include "xv_demosaic.h"
#include "xv_gamma_lut.h"
#include "math.h"
#include "OV5640.h"

#define CAM1_I2C XPAR_IIC_0_BASEADDR
#define CAM2_I2C XPAR_IIC_1_BASEADDR
#define CAM_I2C_ADDRESS 0x3c
#define GPIO_CAM1_PWUP 0b01
#define GPIO_CAM2_PWUP 0b10
#define GPIO_LEDG 0b100
#define IMG_WIDTH 1920
#define IMG_HEIGHT 1080

int init();
int Write_Camera_Reg(UINTPTR, u16, u8);
void Read_Camera_Reg(UINTPTR, u16, u8*);
void Calc_gamma(float);
int Init_Pcam5C(UINTPTR);
void Init_Demosaic(XV_demosaic*, u16);
void Init_Gamma_LUT(XV_gamma_lut*, u16);

enum ErrorState {
    CAMERA_ID, CAMERA_CLKSEL, CAMERA_SOFTPWDN, CAMERA_CFG_INIT, CAMERA_CFG_1080P, CAMERA_CFG_AWB, CAMERA_SOFTPWUP
};
u8 errorState = 0;

XGpio GpioInst;
XV_demosaic DemosaicInst1;
XV_demosaic DemosaicInst2;
XV_gamma_lut GammaLutInst1;
XV_gamma_lut GammaLutInst2;

u16 gamma_reg[1024];

int main() {
    init_platform();

    xil_printf("v2.7\r\n");
    // Initialize the GPIO driver
    int Status = XGpio_Initialize(&GpioInst, XPAR_GPIO_0_DEVICE_ID);
    if (Status != XST_SUCCESS) {
        return Status;
    }

    // Green LED off
    XGpio_DiscreteSet(&GpioInst, 1, GPIO_LEDG);

    Status = init();

    if (Status == XST_SUCCESS) {
        xil_printf("Init success\r\n");
        // Green LED on
        XGpio_DiscreteClear(&GpioInst, 1, GPIO_LEDG);
    } else {
        xil_printf("Init failed:errState %d\r\n",errorState);
    }

    cleanup_platform();
    return 0;
}

int init() {
    int Status = XST_SUCCESS;

    // Reset Cameras
    XGpio_DiscreteClear(&GpioInst, 1, GPIO_CAM1_PWUP | GPIO_CAM2_PWUP);
    usleep(100000);
    // PWUP Camera 1
    XGpio_DiscreteSet(&GpioInst, 1, GPIO_CAM1_PWUP);
    usleep(50000);
    // PWUP Camera 2
    XGpio_DiscreteSet(&GpioInst, 1, GPIO_CAM2_PWUP);
    usleep(50000);
    xil_printf("Cam reset done\r\n");

    Status = Init_Pcam5C(CAM1_I2C);
    if (Status != XST_SUCCESS) {
        return Status;
    }
    xil_printf("Cam1 done\r\n");

    Status = Init_Pcam5C(CAM2_I2C);
    if (Status != XST_SUCCESS) {
        return Status;
    }
    xil_printf("Cam2 done\r\n");

    Init_Demosaic(&DemosaicInst1, XPAR_XV_DEMOSAIC_0_DEVICE_ID);
    Init_Demosaic(&DemosaicInst2, XPAR_XV_DEMOSAIC_1_DEVICE_ID);
    xil_printf("Init_Demosaic done\r\n");

    Calc_gamma(1.6);
    Init_Gamma_LUT(&GammaLutInst1, XPAR_XV_GAMMA_LUT_0_DEVICE_ID);
    Init_Gamma_LUT(&GammaLutInst2, XPAR_XV_GAMMA_LUT_1_DEVICE_ID);
    xil_printf("Init_Gamma_LUT done\r\n");

    return XST_SUCCESS;
}

int Write_Camera_Reg(UINTPTR BaseAddr, u16 regAddr, u8 regVal) {
    u8 sendData[3] = { (u8) (regAddr >> 8), (u8) (regAddr & 0xff), regVal };
    u8 buf;
    // Send regVal to regAddr
    XIic_Send(BaseAddr, CAM_I2C_ADDRESS, sendData, 3, XIIC_STOP);
    XIic_WriteReg(BaseAddr, XIIC_CR_REG_OFFSET, XIIC_CR_TX_FIFO_RESET_MASK);
    usleep(50);
    // Confirm the written data @ regAddr
    XIic_Send(BaseAddr, CAM_I2C_ADDRESS, sendData, 2, XIIC_REPEATED_START);
    //XIic_Send(BaseAddr, CAM_I2C_ADDRESS, sendData, 2, XIIC_STOP);
    XIic_Recv(BaseAddr, CAM_I2C_ADDRESS, &buf, 1, XIIC_STOP);

    if (regAddr == 0x3008) {
        return XST_SUCCESS;
    } else if (regVal != buf) {
        //xil_printf("Write reg failed @ 0x%04x\r\n", regAddr);
        return XST_FAILURE;
    }
    return XST_SUCCESS;
}

void Read_Camera_Reg(UINTPTR BaseAddr, u16 regAddr, u8 *val) {
    u8 regAddrOrd[2] = { (u8) (regAddr >> 8), (u8) (regAddr & 0xff) };
    XIic_Send(BaseAddr, CAM_I2C_ADDRESS, regAddrOrd, 2, XIIC_REPEATED_START);
    XIic_Recv(BaseAddr, CAM_I2C_ADDRESS, val, 1, XIIC_STOP);
}

void Calc_gamma(float gamma_val) {
    for (int i = 0; i < 1024; i++) {
        gamma_reg[i] = (pow((i / 1024.0), (1 / gamma_val)) * 1024.0);
    }
}

int Init_Pcam5C(UINTPTR Camera_I2C) {
    int Status = XST_SUCCESS;

    u8 buf[2];
    Read_Camera_Reg(Camera_I2C, 0x300a, &buf[0]);
    Read_Camera_Reg(Camera_I2C, 0x300b, &buf[1]);

    if ((buf[0] != 0x56) || (buf[1] != 0x40)) {
        errorState = CAMERA_ID;
        return XST_FAILURE;
    }

    Status = Write_Camera_Reg(Camera_I2C, 0x3103, 0x11);
    if (Status != XST_SUCCESS) {
        errorState = CAMERA_CLKSEL;
        return Status;
    }
    usleep(10);

    Status = Write_Camera_Reg(Camera_I2C, 0x3008, 0x82);
    if (Status != XST_SUCCESS) {
        errorState = CAMERA_SOFTPWDN;
        return Status;
    }

    usleep(10000);

    u8 word_counter = 0;
    while (cfg_init[word_counter].addr != 0xffff) {
        Status |= Write_Camera_Reg(Camera_I2C, cfg_init[word_counter].addr,
                cfg_init[word_counter].data);
        word_counter++;
        usleep(10);
    }
    if (Status != XST_SUCCESS) {
        errorState = CAMERA_CFG_INIT;
        return Status;
    }

    word_counter = 0;
    while (cfg_1080p_30fps[word_counter].addr != 0xffff) {
        Status |= Write_Camera_Reg(Camera_I2C, cfg_1080p_30fps[word_counter].addr,
                cfg_1080p_30fps[word_counter].data);
        word_counter++;
        usleep(10);
    }
    if (Status != XST_SUCCESS) {
        errorState = CAMERA_CFG_1080P;
        return Status;
    }

    word_counter = 0;
    while (cfg_simple_awb[word_counter].addr != 0xffff) {
        Status |= Write_Camera_Reg(Camera_I2C, cfg_simple_awb[word_counter].addr,
                cfg_simple_awb[word_counter].data);
        word_counter++;
        usleep(10);
    }
    if (Status != XST_SUCCESS) {
        errorState = CAMERA_CFG_AWB;
        return Status;
    }

    Status = Write_Camera_Reg(Camera_I2C, 0x3008, 0x02);
    if (Status != XST_SUCCESS) {
        xil_printf("Camera softPWUP err\r\n");
        return Status;
    }
    usleep(200);

    return Status;
}

void Init_Demosaic(XV_demosaic *XV_demosaic_inst, u16 DeviceId) {
    XV_demosaic_Initialize(XV_demosaic_inst, DeviceId);
    XV_demosaic_Set_HwReg_bayer_phase(XV_demosaic_inst, 3);
    XV_demosaic_Set_HwReg_width(XV_demosaic_inst, IMG_WIDTH);
    XV_demosaic_Set_HwReg_height(XV_demosaic_inst, IMG_HEIGHT);
    XV_demosaic_EnableAutoRestart(XV_demosaic_inst);
    XV_demosaic_Start(XV_demosaic_inst);
}

void Init_Gamma_LUT(XV_gamma_lut *XV_gamma_lut_inst, u16 DeviceId) {
    XV_gamma_lut_Initialize(XV_gamma_lut_inst, DeviceId);
    XV_gamma_lut_Set_HwReg_video_format(XV_gamma_lut_inst, 0);
    XV_gamma_lut_Set_HwReg_width(XV_gamma_lut_inst, IMG_WIDTH);
    XV_gamma_lut_Set_HwReg_height(XV_gamma_lut_inst, IMG_HEIGHT);
    XV_gamma_lut_Write_HwReg_gamma_lut_0_Bytes(XV_gamma_lut_inst, 0, (char *) gamma_reg, 2048);
    XV_gamma_lut_Write_HwReg_gamma_lut_1_Bytes(XV_gamma_lut_inst, 0, (char *) gamma_reg, 2048);
    XV_gamma_lut_Write_HwReg_gamma_lut_2_Bytes(XV_gamma_lut_inst, 0, (char *) gamma_reg, 2048);
    XV_gamma_lut_EnableAutoRestart(XV_gamma_lut_inst);
    XV_gamma_lut_Start(XV_gamma_lut_inst);
}

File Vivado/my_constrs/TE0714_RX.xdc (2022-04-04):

set_property BITSTREAM.GENERAL.COMPRESS TRUE [current_design]
set_property BITSTREAM.CONFIG.CONFIGRATE 66 [current_design]
set_property BITSTREAM.CONFIG.SPI_32BIT_ADDR NO [current_design]
set_property BITSTREAM.CONFIG.SPI_BUSWIDTH 4 [current_design]
set_property BITSTREAM.CONFIG.M1PIN PULLNONE [current_design]
set_property BITSTREAM.CONFIG.M2PIN PULLNONE [current_design]
set_property BITSTREAM.CONFIG.M0PIN PULLNONE [current_design]
set_property BITSTREAM.CONFIG.USR_ACCESS TIMESTAMP [current_design]
set_property CONFIG_VOLTAGE 1.8 [current_design]
set_property CFGBVS GND [current_design]

set_property -dict {PACKAGE_PIN T14 IOSTANDARD LVCMOS18} [get_ports sys_clock]
set_property -dict {PACKAGE_PIN P18 IOSTANDARD LVCMOS18} [get_ports KEY0]
set_property -dict {PACKAGE_PIN T17 IOSTANDARD LVCMOS18} [get_ports KEY1]
set_property -dict {PACKAGE_PIN U10 IOSTANDARD LVCMOS18} [get_ports GPIO_O]
set_property -dict {PACKAGE_PIN V16 IOSTANDARD LVCMOS18} [get_ports {LED_YELLOW[0]}]
set_property -dict {PACKAGE_PIN V17 IOSTANDARD LVCMOS18} [get_ports {LED_GREEN[0]}]
set_property -dict {PACKAGE_PIN M15 IOSTANDARD LVCMOS18} [get_ports {EN_GTPWR[0]}]
set_property -dict {PACKAGE_PIN M6 IOSTANDARD LVCMOS33} [get_ports {PCIe_CLK_nREQ[0]}]
set_property -dict {PACKAGE_PIN R1 IOSTANDARD LVCMOS33} [get_ports PCIe_nRST]
set_property -dict {PACKAGE_PIN K18 IOSTANDARD LVCMOS18} [get_ports LED_MOD]
set_property PACKAGE_PIN B6 [get_ports {MGT_REFCLK_clk_p[0]}]
set_property PACKAGE_PIN E3 [get_ports {MGT_SERIAL_RX_rxn[0]}]
set_property PACKAGE_PIN D6 [get_ports {PCIe_REFCLK_clk_p[0]}]
set_property PACKAGE_PIN A3 [get_ports {PCIe_SERIAL_rxn[0]}]

set_false_path -from [get_ports KEY0]
set_input_delay 0.000 [get_ports KEY0]
set_false_path -from [get_ports KEY1]
set_input_delay 0 [get_ports KEY1]
set_false_path -from [get_ports PCIe_nRST]
set_input_delay 0 [get_ports PCIe_nRST]
set_false_path -to [get_ports {LED_YELLOW[0]}]
set_output_delay 0.000 [get_ports {LED_YELLOW[0]}]
set_false_path -to [get_ports {LED_GREEN[0]}]
set_output_delay 0.000 [get_ports {LED_GREEN[0]}]
set_false_path -to [get_ports LED_MOD]
set_output_delay 0 [get_ports LED_MOD]
set_false_path -to [get_ports {EN_GTPWR[0]}]
set_output_delay 0.000 [get_ports {EN_GTPWR[0]}]
set_false_path -to [get_ports {PCIe_CLK_nREQ[0]}]
set_output_delay 0 [get_ports {PCIe_CLK_nREQ[0]}]

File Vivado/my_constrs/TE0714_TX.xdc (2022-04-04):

set_property BITSTREAM.GENERAL.COMPRESS TRUE [current_design]
set_property BITSTREAM.CONFIG.CONFIGRATE 66 [current_design]
set_property BITSTREAM.CONFIG.SPI_32BIT_ADDR NO [current_design]
set_property BITSTREAM.CONFIG.SPI_BUSWIDTH 4 [current_design]
set_property BITSTREAM.CONFIG.M1PIN PULLNONE [current_design]
set_property BITSTREAM.CONFIG.M2PIN PULLNONE [current_design]
set_property BITSTREAM.CONFIG.M0PIN PULLNONE [current_design]
set_property BITSTREAM.CONFIG.USR_ACCESS TIMESTAMP [current_design]
set_property BITSTREAM.CONFIG.UNUSEDPIN PULLNONE [current_design]
set_property CONFIG_VOLTAGE 1.8 [current_design]
set_property CFGBVS GND [current_design]


set_property -dict {PACKAGE_PIN T14 IOSTANDARD LVCMOS18} [get_ports sys_clock]
set_property -dict {PACKAGE_PIN N18 IOSTANDARD LVCMOS18} [get_ports KEY0]
set_property -dict {PACKAGE_PIN P18 IOSTANDARD LVCMOS18} [get_ports KEY1]
set_property -dict {PACKAGE_PIN K18 IOSTANDARD LVCMOS18} [get_ports LED_MOD]
set_property -dict {PACKAGE_PIN U17 IOSTANDARD LVCMOS18} [get_ports {LED_GREEN[0]}]
set_property -dict {PACKAGE_PIN T17 IOSTANDARD LVCMOS18} [get_ports {LED_YELLOW[0]}]
set_property -dict {PACKAGE_PIN V9 IOSTANDARD LVCMOS18} [get_ports UART_txd]
set_property -dict {PACKAGE_PIN U9 IOSTANDARD LVCMOS18} [get_ports UART_rxd]
set_property -dict {PACKAGE_PIN U6 IOSTANDARD LVCMOS33} [get_ports {BF4M_EN[0]}]
set_property -dict {PACKAGE_PIN M15 IOSTANDARD LVCMOS18} [get_ports {EN_GTPWR[0]}]
set_property -dict {PACKAGE_PIN L4 IOSTANDARD LVCMOS33} [get_ports CAM1_I2C_scl_io]
set_property -dict {PACKAGE_PIN L3 IOSTANDARD LVCMOS33} [get_ports CAM1_I2C_sda_io]
set_property -dict {PACKAGE_PIN K6 IOSTANDARD LVCMOS33} [get_ports CAM2_I2C_scl_io]
set_property -dict {PACKAGE_PIN K5 IOSTANDARD LVCMOS33} [get_ports CAM2_I2C_sda_io]
set_property -dict {PACKAGE_PIN K3 IOSTANDARD LVCMOS33} [get_ports {CAM1_PWUP[0]}]
set_property -dict {PACKAGE_PIN J5 IOSTANDARD LVCMOS33} [get_ports {CAM2_PWUP[0]}]

set_property INTERNAL_VREF 0.6 [get_iobanks 15]

set_property -dict {PACKAGE_PIN E16 IOSTANDARD LVDS_25} [get_ports MIPI_CSI_CAM1_clk_hs_p]
set_property -dict {PACKAGE_PIN F18 IOSTANDARD HSUL_12} [get_ports MIPI_CSI_CAM1_clk_lp_p]
set_property -dict {PACKAGE_PIN E17 IOSTANDARD HSUL_12} [get_ports MIPI_CSI_CAM1_clk_lp_n]
set_property -dict {PACKAGE_PIN B16 IOSTANDARD LVDS_25} [get_ports {MIPI_CSI_CAM1_data_hs_p[0]}]
set_property -dict {PACKAGE_PIN C17 IOSTANDARD LVDS_25} [get_ports {MIPI_CSI_CAM1_data_hs_p[1]}]
set_property -dict {PACKAGE_PIN B17 IOSTANDARD HSUL_12} [get_ports {MIPI_CSI_CAM1_data_lp_p[0]}]
set_property -dict {PACKAGE_PIN B15 IOSTANDARD HSUL_12} [get_ports {MIPI_CSI_CAM1_data_lp_n[0]}]
set_property -dict {PACKAGE_PIN D18 IOSTANDARD HSUL_12} [get_ports {MIPI_CSI_CAM1_data_lp_p[1]}]
set_property -dict {PACKAGE_PIN C16 IOSTANDARD HSUL_12} [get_ports {MIPI_CSI_CAM1_data_lp_n[1]}]

set_property -dict {PACKAGE_PIN E13 IOSTANDARD LVDS_25} [get_ports MIPI_CSI_CAM2_clk_hs_p]
set_property -dict {PACKAGE_PIN A9 IOSTANDARD HSUL_12} [get_ports MIPI_CSI_CAM2_clk_lp_p]
set_property -dict {PACKAGE_PIN B11 IOSTANDARD HSUL_12} [get_ports MIPI_CSI_CAM2_clk_lp_n]
set_property -dict {PACKAGE_PIN D11 IOSTANDARD LVDS_25} [get_ports {MIPI_CSI_CAM2_data_hs_p[0]}]
set_property -dict {PACKAGE_PIN D8 IOSTANDARD LVDS_25} [get_ports {MIPI_CSI_CAM2_data_hs_p[1]}]
set_property -dict {PACKAGE_PIN D9 IOSTANDARD HSUL_12} [get_ports {MIPI_CSI_CAM2_data_lp_p[0]}]
set_property -dict {PACKAGE_PIN G16 IOSTANDARD HSUL_12} [get_ports {MIPI_CSI_CAM2_data_lp_n[0]}]
set_property -dict {PACKAGE_PIN C9 IOSTANDARD HSUL_12} [get_ports {MIPI_CSI_CAM2_data_lp_p[1]}]
set_property -dict {PACKAGE_PIN C11 IOSTANDARD HSUL_12} [get_ports {MIPI_CSI_CAM2_data_lp_n[1]}]
set_property PACKAGE_PIN B6 [get_ports GT_REFCLK_clk_p]
set_property PACKAGE_PIN H2 [get_ports {GT_SERIAL_TX_txp[0]}]



set_property C_CLK_INPUT_FREQ_HZ 300000000 [get_debug_cores dbg_hub]
set_property C_ENABLE_CLK_DIVIDER false [get_debug_cores dbg_hub]
set_property C_USER_SCAN_CHAIN 1 [get_debug_cores dbg_hub]
connect_debug_port dbg_hub/clk [get_nets clk]

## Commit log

2022-04-04 Add explanations on PCB/Schematic
2022-04-24 RX PCB
    [RX_module.kicad_pcb]
2022-04-24 Add raspberry pi os submodule
